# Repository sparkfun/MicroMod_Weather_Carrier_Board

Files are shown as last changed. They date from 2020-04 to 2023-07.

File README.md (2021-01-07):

SparkFun MicroMod Weather Carrier Board
========================================

SparkFun MicroMod Weather Carrier Board

[*SparkFun MicroMod Weather Carrier Board (SEN-16794)*](https://www.sparkfun.com/products/16794)

The MicroMod Weather Carrier Board for the [SparkFun MicroMod Ecosystem](https://www.sparkfun.com/micromod) allows you to create your own weather station with one of a multitude of processors. The carrier board includes three sensors: the BME280 temperature, pressure and humidity sensor, the VEML6075 UV sensor and the AS3935 Lightning detector. There is also a 3-pin latch terminal to add an external [soil moisture sensor](https://www.sparkfun.com/products/13637), a pair RJ11 jacks to plug in the wind and rain sensors included with our [Weather Meter Kit](https://www.sparkfun.com/products/15901) as well as a microSD card slot so you can plug in an SD card to log the weather data.

Repository Contents
-------------------

* **/Documentation** - Data sheets, additional product information 
* **/Hardware** - Eagle design files (.brd, .sch)
* **/Production** - Production panel files (.brd)
* **/Examples** - Arduino examples for the MicroMod Weather Carrier Board

Documentation
--------------
* **Libraries** - Arduino libraries required for the MicroMod Weather Carrier Board.
   * **[BME280 Library](https://github.com/sparkfun/SparkFun_BME280_Arduino_Library)** - Arduino Library for the BME280.
   * **[VEML6075 Library](https://github.com/sparkfun/SparkFun_VEML6075_Arduino_Library)** - Arduino library for the VEML6075.
   * **[AS3935 Library](https://github.com/sparkfun/SparkFun_AS3935_Lightning_Detector_Arduino_Library)** - Arduino library for the AS3935.
* **[Hookup Guide](https://learn.sparkfun.com/tutorials/micromod-weather-carrier-board-hookup-guide)** - Basic hookup guide for the MicroMod Weather Carrier Board.
* **[SparkFun Fritzing repo](https://github.com/sparkfun/Fritzing_Parts)** - Fritzing diagrams for SparkFun products.
* **[SparkFun 3D Model repo](https://github.com/sparkfun/3D_Models)** - 3D models of SparkFun products. 
* **[SparkFun Graphical Datasheets](https://github.com/sparkfun/Graphical_Datasheets)** -Graphical Datasheets for various SparkFun products.

Product Versions
----------------
* [SEN-16794](https://www.sparkfun.com/products/16794)- Initial release of the MicroMod Weather Carrier Board.

License Information
-------------------

This product is _**open source**_! 

Please review the LICENSE.md file for license information. 

If you have any questions or concerns on licensing, please contact technical support on our [SparkFun forums](https://forum.sparkfun.com/viewforum.php?f=152).

Distributed as-is; no warranty is given.

- Your friends at SparkFun.

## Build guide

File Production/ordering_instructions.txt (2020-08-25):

panel size, 169x125mm
PCB thickness, 1.6mm
number of layers, 2
soldermask color, Red
silkscreen color, White
oz copper, 1oz
finish, HASL lead free
stencils, top
pcs per panel, 4
min trace width, 0.2032mm / 0.0080in
min drill size, 0.3048mm / 0.0120in

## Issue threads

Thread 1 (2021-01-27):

Davis Anemometer

dartmoordunbar, 2021-01-27:
Is there any way to use a Davis instruments Anemometer with this?

makin-stuff, 2022-01-18:
Hi there @dartmoordunbar. The MM Weather CB and the Arduino examples in this repo are specifically designed for this weather meter: https://www.sparkfun.com/products/15901
Simply plug the connectors into the RJ11 jacks.

Closed 2022-01-18.

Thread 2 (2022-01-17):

MM_Weather_CB_Test code does not compile for Artemis module.

phillipjohnston, 2022-01-17:
```
/Users/phillip/src/ea/projects/MicroMod_Weather_Carrier_Board/Examples/MM_Weather_CB_Test/MM_Weather_CB_Test.ino: In function 'void setup()':
MM_Weather_CB_Test:116:3: error: 'interrupts' was not declared in this scope
   interrupts();
   ^~~~~~~~~~
/Users/phillip/src/ea/projects/MicroMod_Weather_Carrier_Board/Examples/MM_Weather_CB_Test/MM_Weather_CB_Test.ino:116:3: note: suggested alternative: 'intptr_t'
   interrupts();
   ^~~~~~~~~~
   intptr_t
```

This is using the Apollo3 boards package 2.2.0, witih the Artemis Micromod Processor selected.

Library versions:

```
  -> candidates: [SPI@2.0.0]
/Users/phillip/Library/Arduino15/packages/SparkFun/tools/arm-none-eabi-gcc/8-2018-q4-major/bin/arm-none-eabi-g++ -include /Users/phillip/Library/Arduino15/packages/SparkFun/hardware/apollo3/2.2.0/variants/SFE_ARTEMIS_MM_PB/mbed/mbed_config.h -include /Users/phillip/Library/Arduino15/packages/SparkFun/hardware/apollo3/2.2.0/cores/arduino/sdk/ArduinoSDK.h -iprefix /Users/phillip/Library/Arduino15/packages/SparkFun/hardware/apollo3/2.2.0/cores/ @/Users/phillip/Library/Arduino15/packages/SparkFun/hardware/apollo3/2.2.0/variants/SFE_ARTEMIS_MM_PB/mbed/.cxx-flags -w -x c++ -E -CC -DARDUINO=10819 -DARDUINO_APOLLO3_SFE_ARTEMIS_MM_PB -DARDUINO_ARCH_MBED -DARDUINO_ARCH_APOLLO3 -DMBED_NO_GLOBAL_USING_DIRECTIVE -DCORDIO_ZERO_COPY_HCI @/Users/phillip/Library/Arduino15/packages/SparkFun/hardware/apollo3/2.2.0/variants/SFE_ARTEMIS_MM_PB/mbed/.cxx-symbols -I/Users/phillip/Library/Arduino15/packages/SparkFun/hardware/apollo3/2.2.0/cores/arduino -I/Users/phillip/Library/Arduino15/packages/SparkFun/hardware/apollo3/2.2.0/variants/SFE_ARTEMIS_MM_PB -I/Users/phillip/Library/Arduino15/packages/SparkFun/hardware/apollo3/2.2.0/libraries/Wire/src -I/Users/phillip/Library/Arduino15/packages/SparkFun/hardware/apollo3/2.2.0/libraries/SPI/src -I/Users/phillip/Library/Arduino15/packages/SparkFun/hardware/apollo3/2.2.0/cores/arduino -I/Users/phillip/Library/Arduino15/packages/SparkFun/hardware/apollo3/2.2.0/cores/arduino/mbed-bridge -I/Users/phillip/Library/Arduino15/packages/SparkFun/hardware/apollo3/2.2.0/cores/arduino/mbed-bridge/core-api -I/Users/phillip/Library/Arduino15/packages/SparkFun/hardware/apollo3/2.2.0/cores/arduino/mbed-bridge/core-api/api/deprecated @/Users/phillip/Library/Arduino15/packages/SparkFun/hardware/apollo3/2.2.0/variants/SFE_ARTEMIS_MM_PB/mbed/.includes /var/folders/t_/9hrr7dnd7g5gqkc3lnlv0qx40000gn/T/arduino_build_899532/sketch/MM_Weather_CB_Test.ino.cpp -o /dev/null
Alternatives for SparkFunBME280.h: [SparkFun_BME280@2.0.9]
ResolveLibrary(SparkFunBME280.h)
  -> candidates: [SparkFun_BME280@2.0.9]
/Users/phillip/Library/Arduino15/packages/SparkFun/tools/arm-none-eabi-gcc/8-2018-q4-major/bin/arm-none-eabi-g++ -include /Users/phillip/Library/Arduino15/packages/SparkFun/hardware/apollo3/2.2.0/variants/SFE_ARTEMIS_MM_PB/mbed/mbed_config.h -include /Users/phillip/Library/Arduino15/packages/SparkFun/hardware/apollo3/2.2.0/cores/arduino/sdk/ArduinoSDK.h -iprefix /Users/phillip/Library/Arduino15/packages/SparkFun/hardware/apollo3/2.2.0/cores/ @/Users/phillip/Library/Arduino15/packages/SparkFun/hardware/apollo3/2.2.0/variants/SFE_ARTEMIS_MM_PB/mbed/.cxx-flags -w -x c++ -E -CC -DARDUINO=10819 -DARDUINO_APOLLO3_SFE_ARTEMIS_MM_PB -DARDUINO_ARCH_MBED -DARDUINO_ARCH_APOLLO3 -DMBED_NO_GLOBAL_USING_DIRECTIVE -DCORDIO_ZERO_COPY_HCI @/Users/phillip/Library/Arduino15/packages/SparkFun/hardware/apollo3/2.2.0/variants/SFE_ARTEMIS_MM_PB/mbed/.cxx-symbols -I/Users/phillip/Library/Arduino15/packages/SparkFun/hardware/apollo3/2.2.0/cores/arduino -I/Users/phillip/Library/Arduino15/packages/SparkFun/hardware/apollo3/2.2.0/variants/SFE_ARTEMIS_MM_PB -I/Users/phillip/Library/Arduino15/packages/SparkFun/hardware/apollo3/2.2.0/libraries/Wire/src -I/Users/phillip/Library/Arduino15/packages/SparkFun/hardware/apollo3/2.2.0/libraries/SPI/src -I/Users/phillip/Documents/Arduino/libraries/SparkFun_BME280/src -I/Users/phillip/Library/Arduino15/packages/SparkFun/hardware/apollo3/2.2.0/cores/arduino -I/Users/phillip/Library/Arduino15/packages/SparkFun/hardware/apollo3/2.2.0/cores/arduino/mbed-bridge -I/Users/phillip/Library/Arduino15/packages/SparkFun/hardware/apollo3/2.2.0/cores/arduino/mbed-bridge/core-api -I/Users/phillip/Library/Arduino15/packages/SparkFun/hardware/apollo3/2.2.0/cores/arduino/mbed-bridge/core-api/api/deprecated @/Users/phillip/Library/Arduino15/packages/SparkFun/hardware/apollo3/2.2.0/variants/SFE_ARTEMIS_MM_PB/mbed/.includes /var/folders/t_/9hrr7dnd7g5gqkc3lnlv0qx40000gn/T/arduino_build_899532/sketch/MM_Weather_CB_Test.ino.cpp -o /dev/null
Alternatives for SparkFun_VEML6075_Arduino_Library.h: [SparkFun_VEML6075_Arduino_Library@1.1.4]
ResolveLibrary(SparkFun_VEML6075_Arduino_Library.h)
  -> candidates: [SparkFun_VEML6075_Arduino_Library@1.1.4]
/Users/phillip/Library/Arduino15/packages/SparkFun/tools/arm-none-eabi-gcc/8-2018-q4-major/bin/arm-none-eabi-g++ -include /Users/phillip/Library/Arduino15/packages/SparkFun/hardware/apollo3/2.2.0/variants/SFE_ARTEMIS_MM_PB/mbed/mbed_config.h -include /Users/phillip/Library/Arduino15/packages/SparkFun/hardware/apollo3/2.2.0/cores/arduino/sdk/ArduinoSDK.h -iprefix /Users/phillip/Library/Arduino15/packages/SparkFun/hardware/apollo3/2.2.0/cores/ @/Users/phillip/Library/Arduino15/packages/SparkFun/hardware/apollo3/2.2.0/variants/SFE_ARTEMIS_MM_PB/mbed/.cxx-flags -w -x c++ -E -CC -DARDUINO=10819 -DARDUINO_APOLLO3_SFE_ARTEMIS_MM_PB -DARDUINO_ARCH_MBED -DARDUINO_ARCH_APOLLO3 -DMBED_NO_GLOBAL_USING_DIRECTIVE -DCORDIO_ZERO_COPY_HCI @/Users/phillip/Library/Arduino15/packages/SparkFun/hardware/apollo3/2.2.0/variants/SFE_ARTEMIS_MM_PB/mbed/.cxx-symbols -I/Users/phillip/Library/Arduino15/packages/SparkFun/hardware/apollo3/2.2.0/cores/arduino -I/Users/phillip/Library/Arduino15/packages/SparkFun/hardware/apollo3/2.2.0/variants/SFE_ARTEMIS_MM_PB -I/Users/phillip/Library/Arduino15/packages/SparkFun/hardware/apollo3/2.2.0/libraries/Wire/src -I/Users/phillip/Library/Arduino15/packages/SparkFun/hardware/apollo3/2.2.0/libraries/SPI/src -I/Users/phillip/Documents/Arduino/libraries/SparkFun_BME280/src -I/Users/phillip/Documents/Arduino/libraries/SparkFun_VEML6075_Arduino_Library/src -I/Users/phillip/Library/Arduino15/packages/SparkFun/hardware/apollo3/2.2.0/cores/arduino -I/Users/phillip/Library/Arduino15/packages/SparkFun/hardware/apollo3/2.2.0/cores/arduino/mbed-bridge -I/Users/phillip/Library/Arduino15/packages/SparkFun/hardware/apollo3/2.2.0/cores/arduino/mbed-bridge/core-api -I/Users/phillip/Library/Arduino15/packages/SparkFun/hardware/apollo3/2.2.0/cores/arduino/mbed-bridge/core-api/api/deprecated @/Users/phillip/Library/Arduino15/packages/SparkFun/hardware/apollo3/2.2.0/variants/SFE_ARTEMIS_MM_PB/mbed/.includes /var/folders/t_/9hrr7dnd7g5gqkc3lnlv0qx40000gn/T/arduino_build_899532/sketch/MM_Weather_CB_Test.ino.cpp -o /dev/null
Alternatives for SparkFun_AS3935.h: [SparkFun_AS3935_Lightning_Detector_Arduino_Library@1.4.3]
ResolveLibrary(SparkFun_AS3935.h)
  -> candidates: [SparkFun_AS3935_Lightning_Detector_Arduino_Library@1.4.3]
```

phillipjohnston, 2022-01-17:
Related to: https://github.com/sparkfun/Arduino_Apollo3/issues/431

Of course, commenting out resolves compilation, but I do not understand the core/example/library implementations enough to know whether this introduces unexpected behavior.

santaimpersonator, 2022-03-31:
@phillipjohnston

We implemented a fix (https://github.com/sparkfun/Arduino_Apollo3/issues/431#issuecomment-1071055401) for the interrupt enable/disable functions. Please try updating the Arduino core version, in the Board Manager, before re-uploading the code to your processor board.

If you let us know which [example](https://github.com/sparkfun/MicroMod_Weather_Carrier_Board/tree/master/Examples) you are using and provide a screenshot (or copy) of the output in the Serial Monitor, I can at least try to verify that we am seeing the something similar with a test setup.

phillipjohnston, 2022-05-05:
Confirmed the example now compiles without modification.

Closed 2022-05-05.

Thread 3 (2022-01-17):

Wind direction interpretation clearly not degrees

phillipjohnston, 2022-01-17:
Is the wind direction supposed to correspond to degrees? When I try to use the example with an ESP32, 75% of the range returns a value of -1, and the remaining 25% is all over the place. With an Artemis, I only get numbers in specific ranges - never anything representing 0-180.

makin-stuff, 2022-01-18:
Hello @phillipjohnston. Are you plugging in a weather meter to the RJ11 jacks?  The hardware and Arduino examples are designed specifically for this one: https://www.sparkfun.com/products/15901

phillipjohnston, 2022-01-18:
Yep, that's the one I'm using!

phillipjohnston, 2022-05-05:
I am using `MM_Weather_CB_Test` to check this behavior. With the latest Apollo3 board files update, the behavior is different. I now see values in the range of [0, 300] (never get above 300). However, the wind direction still does not seem to correspond to a consistent set of readings as far as I can tell - for example, I can never find any degrees above 300, and there only seems to be a few values that ever get reported, regardless of how precisely I turn the wind vane: 113, 23, 224, 248 are common values that appear. It is hard to see anything obvious in this from the log without a corresponding video setup showing how things are being turned on the weather vane... but I do not have a good recording setup to get all of that.

Log sample:

```
10:34:41.746 -> Temperature: 79.39
10:34:41.746 -> Humidity: 31
10:34:41.784 -> Pressure: 88734
10:34:41.784 -> Altitude: 3625.9
10:34:41.784 -> UV A, B, index: %4.2f, %4.2f, %4.2f
10:34:41.784 -> Soil Moisture = 122
10:34:41.784 -> Wind direction: 113 degrees
10:34:44.817 ->
10:34:47.851 ->
10:34:47.851 -> Temperature: 79.38
10:34:47.851 -> Humidity: 31
10:34:47.851 -> Pressure: 88730
10:34:47.851 -> Altitude: 3627.2
10:34:47.851 -> UV A, B, index: %4.2f, %4.2f, %4.2f
10:34:47.851 -> Soil Moisture = 173
10:34:47.885 -> Wind direction: 23 degrees
10:34:47.885 -> Rain click!
10:34:47.885 -> Disturber.
10:34:50.889 ->
10:34:53.958 ->
10:34:56.985 ->
10:34:56.985 -> Temperature: 79.34
10:34:56.985 -> Humidity: 31
10:34:56.985 -> Pressure: 88730
10:34:56.985 -> Altitude: 3626.9
10:34:56.985 -> UV A, B, index: %4.2f, %4.2f, %4.2f
10:34:56.985 -> Soil Moisture = 200
10:34:57.019 -> Wind direction: 45 degrees
10:34:57.019 -> Rain click!
10:35:00.022 ->
10:35:00.022 -> Temperature: 79.34
10:35:00.022 -> Humidity: 31
10:35:00.022 -> Pressure: 88727
10:35:00.022 -> Altitude: 3628.0
10:35:00.022 -> UV A, B, index: %4.2f, %4.2f, %4.2f
10:35:00.060 -> Soil Moisture = 132
10:35:00.060 -> Wind direction: 0 degrees
10:35:03.090 ->
10:35:03.090 -> Temperature: 79.32
10:35:03.090 -> Humidity: 31
10:35:03.090 -> Pressure: 88731
10:35:03.090 -> Altitude: 3626.7
10:35:03.090 -> UV A, B, index: %4.2f, %4.2f, %4.2f
10:35:03.090 -> Soil Moisture = 252
10:35:03.090 -> Wind direction: 0 degrees
10:35:06.123 ->
10:35:09.157 ->
10:35:12.209 -> Temperature: 79.27
10:35:12.209 -> Humidity: 31
10:35:12.209 -> Pressure: 88733
10:35:12.209 -> Altitude: 3626.0
10:35:12.209 -> UV A, B, index: %4.2f, %4.2f, %4.2f
10:35:12.209 -> Soil Moisture = 219
10:35:12.242 -> Wind direction: 23 degrees
10:35:12.242 -> Rain click!
10:35:12.242 -> Disturber.
10:35:15.237 ->
10:35:18.285 ->
10:35:24.386 ->
10:35:30.474 ->
10:35:42.651 ->
10:35:48.727 ->
10:36:13.090 ->
10:36:16.139 ->
10:36:16.139 -> Temperature: 79.32
10:36:16.139 -> Humidity: 31
10:36:16.139 -> Pressure: 88731
10:36:16.139 -> Altitude: 3626.7
10:36:16.139 -> UV A, B, index: %4.2f, %4.2f, %4.2f
10:36:16.139 -> Soil Moisture = 254
10:36:16.139 -> Wind direction: 248 degrees
10:36:16.139 -> Rain click!
10:36:19.171 ->
10:36:25.269 ->
10:36:25.269 -> Temperature: 79.30
10:36:25.269 -> Humidity: 31
10:36:25.269 -> Pressure: 88730
10:36:25.269 -> Altitude: 3627.1
10:36:25.269 -> UV A, B, index: %4.2f, %4.2f, %4.2f
10:36:25.269 -> Soil Moisture = 264
10:36:25.269 -> Wind direction: 248 degrees
10:36:49.600 ->
10:36:49.600 -> Temperature: 79.30
10:36:49.600 -> Humidity: 31
10:36:49.600 -> Pressure: 88736
10:36:49.600 -> Altitude: 3625.4
10:36:49.600 -> UV A, B, index: %4.2f, %4.2f, %4.2f
10:36:49.637 -> Soil Moisture = 133
10:36:49.637 -> Wind direction: 113 degrees
10:36:49.637 -> Rain click!
10:36:52.666 ->
10:36:52.666 -> Temperature: 79.30
10:36:52.666 -> Humidity: 31
10:36:52.666 -> Pressure: 88730
10:36:52.666 -> Altitude: 3627.1
10:36:52.666 -> UV A, B, index: %4.2f, %4.2f, %4.2f
10:36:52.666 -> Soil Moisture = 149
10:36:52.666 -> Wind direction: 113 degrees
10:36:55.707 ->
10:36:55.707 -> Temperature: 79.29
10:36:55.707 -> Humidity: 31
10:36:55.707 -> Pressure: 88735
10:36:55.707 -> Altitude: 3625.6
10:36:55.707 -> UV A, B, index: %4.2f, %4.2f, %4.2f
10:36:55.707 -> Soil Moisture = 270
10:36:55.707 -> Wind direction: 113 degrees
10:36:58.752 ->
10:36:58.752 -> Temperature: 79.29
10:36:58.752 -> Humidity: 31
10:36:58.752 -> Pressure: 88734
10:36:58.752 -> Altitude: 3625.8
10:36:58.752 -> UV A, B, index: %4.2f, %4.2f, %4.2f
10:36:58.752 -> Soil Moisture = 251
10:36:58.752 -> Wind direction: 248 degrees
10:36:58.789 -> Rain click!
10:36:58.789 -> Disturber.
10:37:01.804 ->
10:37:01.804 -> Temperature: 79.25
10:37:01.804 -> Humidity: 31
10:37:01.804 -> Pressure: 88731
10:37:01.804 -> Altitude: 3626.7
10:37:01.804 -> UV A, B, index: %4.2f, %4.2f, %4.2f
10:37:01.804 -> Soil Moisture = 241
10:37:01.804 -> Wind direction: 248 degrees
```

phillipjohnston, 2022-05-05:
Now, it may very well be that the interrupt behavior reported in #4 is messing with things.

makin-stuff, 2022-05-05:
Hi there @phillipjohnston. I would highly recommend checking out the documentation on the weather meter ([hookup guide](https://learn.sparkfun.com/tutorials/weather-meter-hookup-guide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) and [datasheet](https://cdn.sparkfun.com/assets/d/1/e/0/6/DS-15901-Weather_Meter.pdf)).

The wind vane basically functions as a voltage divider. So I think you would want to read the analog voltage on the WDIR/A1 pin. Then, the voltage divider equation is: Vo = (Vi*R2)/(R1+R2). Vo is measured from A1, Vi = 3.3V, and R1 is 10k (from schematic). You can calculate R2 and look it up in this table from the datasheet:
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

Hope this helps!

phillipjohnston, 2022-05-05:
Right, I'm happy to do that myself. I'm just pointing out that the example code doesn't work as expected.

phillipjohnston, 2022-05-05:
Although, now that I reread the reviews on the product page (https://www.sparkfun.com/products/15901), I see that this behavior is observed by others and maybe that's just the best it can be.

santaimpersonator, 2023-06-16:
@phillipjohnston
The ADC on the ESP32 is non-linear, which causes issues with the readings. I'd recommend reading and printing out the ADC values, while spinning the wind vane around. If you create a histogram chart (binsize<20), you should be able to see distinct peaks of the indicated directions (which would allow you to fix the example code).

Also, it has a 12-bit ADC (0-4095).

Closed 2022-05-05.

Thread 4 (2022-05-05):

MM_Weather_CB_Test panic if interrupts are enabled.

phillipjohnston, 2022-05-05:
After #2, the code compiles without modification. However, the application panics when interrupts are enabled. Commenting it out removes this error.

```
10:32:47.098 -> ++ MbedOS Error Info ++
10:32:47.098 -> Error Status: 0x80FF0144 Code: 324 Module: 255
10:32:47.098 -> Error Message: Assertion failed: status == osOK
10:32:47.098 -> Location: 0x24EE9
10:32:47.098 -> File: mbed-os/rtos/source/ThisThread.cpp+225
10:32:47.098 -> Error Value: 0x0
10:32:47.098 -> Current Thread: main Id: 0x100048E0 Entry: 0x25EF1 StackSize: 0x1000 StackMem: 0x10006560 SP: 0x100074BC
10:32:47.098 -> For more info, visit: https://mbed.com/s/error?error=0x80FF0144&tgt=SFE_ARTEMIS_MM_PB
10:32:47.134 -> -- MbedOS Error Info --
```

makin-stuff, 2022-05-05:
Hi there @phillipjohnston. I'm closing this issue because this error has nothing to do with the hardware of the MM Weather CB but with the processor board your are using with it. Can you please repost this issue on the corresponding github repo for the processor you're using? Thank you.

Closed 2022-05-05.

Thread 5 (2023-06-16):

Feature Request - Battery charger/connector

santaimpersonator, 2023-06-16:
For remote applications, include a battery charger and connector.

That way a [USB solar panel](https://www.sparkfun.com/products/16835) can be connected. Also, we don't have a solar charging solution with a 3.3V output to connect to the board.

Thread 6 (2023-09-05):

Feature Request: 5V/V_USB pin

santaimpersonator, 2023-09-05:
A [customer requested](https://www.sparkfun.com/news/7930#comment-64f7749be550b931fa19f573) that we breakout a `5V` (or `V_USB`) pin on the board.

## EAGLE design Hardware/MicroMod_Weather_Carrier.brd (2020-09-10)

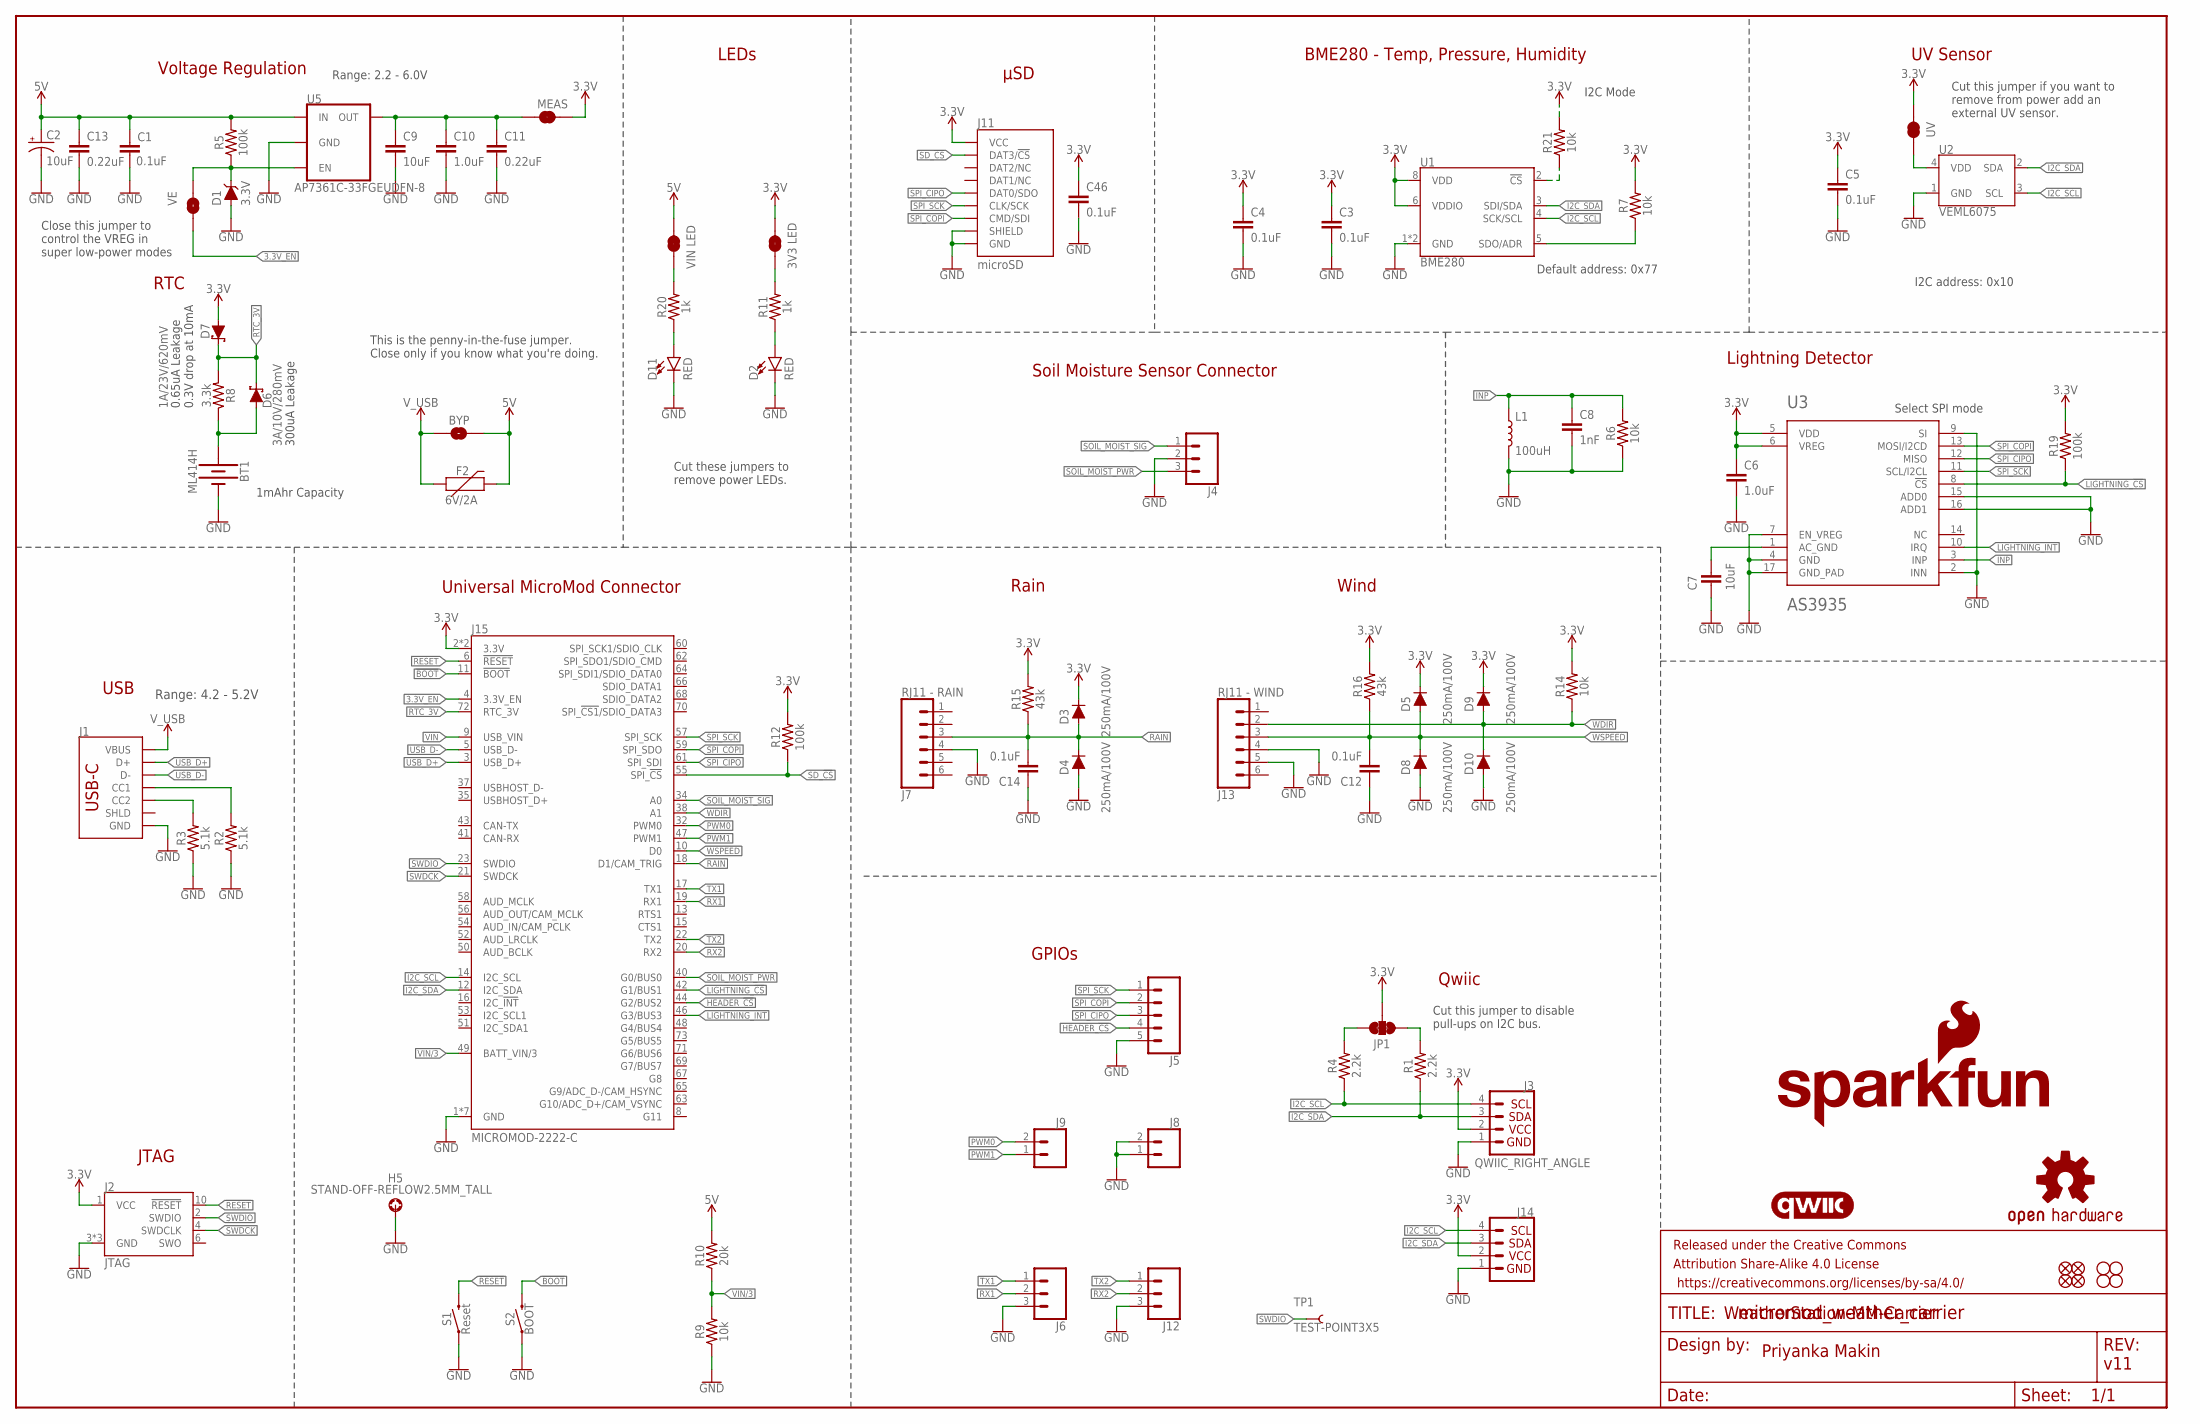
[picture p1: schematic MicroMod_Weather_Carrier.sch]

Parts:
BT1: ML414H; ML414H_IV01E
BYP: JUMPER-SMT_2_NO_SILK; SMT-JUMPER_2_NO_SILK
C1, C3, C4, C5, C12, C14, C46: 0.1uF; 0603
C2: 10uF; EIA3216
C6, C10: 1.0uF; 0603
C7, C9: 10uF; 0603
C8: 1nF; 0603
C11, C13: 0.22uF; 0603
D1: 3.3V; SOD-323
D2, D11: RED; LED-0603
D3, D4, D5, D8, D9, D10: 250mA/100V; SOD-323
D6: 3A/10V/280mV; SOD-323
D7: 1A/23V/620mV; SOD-323
F2: 6V/2A; 1210
FD1, FD2, FD3, FD4: FIDUCIALUFIDUCIAL; FIDUCIAL-MICRO
FRAME1: FRAME-LEDGER; CREATIVE_COMMONS
H1, H2, H3, H4: STAND-OFF
H5: STAND-OFF-REFLOW2.5MM_TALL; STAND-OFF-REFLOW-M2.5
J1: USB_C_2-LAYER_PADS; USB-C-16P-2LAYER-PADS
J2: JTAG; 2X5-PTH-1.27MM
J3: QWIIC_RIGHT_ANGLE; JST04_1MM_RA
J4: CONN_03LATCH; LATCHTERMINAL-5MM-3
J5: CONN_05NO_SILK; 1X05_NO_SILK
J6, J12: CONN_031X03_NO_SILK; 1X03_NO_SILK
J7: RJ11 - RAIN; RJ11-6
J8, J9: CONN_021X02_NO_SILK; 1X02_NO_SILK
J11: microSD; MICRO-SD-SOCKET
J13: RJ11 - WIND; RJ11-6
J14: I2C_STANDARD_NO_SILK; 1X04_NO_SILK
J15: MICROMOD-2222-C; M.2-CONNECTOR-E
JP1: JUMPER-SMT_3_2-NC_TRACE_SILK; SMT-JUMPER_3_2-NC_TRACE_SILK
JP2: VIN LED; SMT-JUMPER_2_NC_TRACE_SILK
JP3: UV; SMT-JUMPER_2_NC_TRACE_SILK
JP4: 3V3 LED; SMT-JUMPER_2_NC_TRACE_SILK
JP6: VE; SMT-JUMPER_2_NO_SILK
L1: 100uH; MA5532-AE
LOGO1: SFE_LOGO_NAME_FLAME.2_INCH; SFE_LOGO_NAME_FLAME_.2
LOGO2: QWIIC_LOGO_CONNECTOR; QWIIC_5.5MM
LOGO3: OSHW-LOGOM; OSHW-LOGO-M
MEAS: JUMPER-COMBO_2_NC_TRACE; COMBO-JUMPER_2_NC_TRACE
R1, R4: 2.2k; 0603
R2, R3: 5.1k; 0603
R5, R12, R19: 100k; 0603
R6, R7, R9, R14, R21: 10k; 0603
R8: 3.3k; 0603
R10: 20k; 0603
R11, R20: 1k; 0603
R15, R16: 43k; 0603
S1: Reset; TACTILE_SWITCH_SMD_5.2MM
S2: BOOT; TACTILE_SWITCH_SMD_5.2MM
TP1: TEST-POINT3X5; PAD.03X.05
U1: BME280; LGA-8-2.5X2.5
U2: VEML6075; VEML6075_A3OP
U3: AS3935; 16LD_MLPQ
U5: AP7361C-33FGEUDFN-8; UDFN-8

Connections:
3.3V: C3.1, C4.1, C5.1, C6.1, C46.1, D3.C, D5.C, D7.A, D9.C, J2.1 (VCC), J3.2, J11.VCC, J14.2, J15.2 (3.3V), J15.74 (3.3V), JP1.2, JP3.2, JP4.2, MEAS.2, MEAS.4 (2), R7.2, R12.2, R14.2, R15.2, R16.2, R19.2, R21.2, U1.6 (VDDIO), U1.8 (VDD), U3.5 (VDD), U3.6 (VREG)
3.3V_EN: J15.4 (3.3V_EN), JP6.1
!BOOT!: J15.11 (!BOOT!), S2.3 (2), S2.4 (2)
!RESET!: J2.10 (!RESET), J15.6 (!RESET!), S1.3 (2), S1.4 (2)
GND: BT1.-, C1.2, C2.-, C3.2, C4.2, C5.2, C6.2, C7.2, C8.2, C9.2, C10.2, C11.2, C12.1, C13.2, C14.1, C46.2, D1.A, D2.C, D4.A, D8.A, D10.A, D11.C, H5.1, J1.GND, J1.GND2 (GND), J2.3 (GND), J2.5 (GND), J2.9 (GND), J3.1, J4.2, J5.5, J6.3, J7.4, J8.1, J8.2, J11.CD1 (SHIELD), J11.GND, J11.GND1 (GND), J11.GND3 (GND), J12.3, J13.4, J13.5, J14.1, J15.1 (GND), J15.7 (GND), J15.33 (GND), J15.36 (GND), J15.39 (GND), J15.45 (GND), J15.75 (GND), L1.2, R2.1, R3.1, R6.1, R9.1, S1.1, S1.2 (1), S2.1, S2.2 (1), U1.1 (GND), U1.7 (GND), U2.1 (GND), U3.2 (INN), U3.4 (GND), U3.7 (EN_VREG), U3.9 (SI), U3.15 (ADD0), U3.16 (ADD1), U3.17 (GND_PAD), U5.4 (GND), U5.EP (GND)
HEADER_!CS!: J5.4, J15.44 (G2/BUS2)
I2C_SCL: J3.4, J14.4, J15.14 (I2C_SCL), R4.1, U1.4 (SCK/SCL), U2.3 (SCL)
I2C_SDA: J3.3, J14.3, J15.12 (I2C_SDA), R1.1, U1.3 (SDI/SDA), U2.2 (SDA)
INP: C8.1, L1.1, R6.2, U3.3 (INP)
LIGHTNING_!CS!: J15.42 (G1/BUS1), R19.1, U3.8 (!CS)
LIGHTNING_INT: J15.46 (G3/BUS3), U3.10 (IRQ)
unnamed: C9.1, C10.1, C11.1, MEAS.1, MEAS.3 (1), U5.1 (OUT)
unnamed: JP1.3, R4.2
unnamed: JP1.1, R1.2
unnamed: JP4.1, R11.2
unnamed: JP2.1, R20.2
unnamed: D2.A, R11.1
unnamed: JP3.1, U2.4 (VDD)
unnamed: R7.1, U1.5 (SDO/ADR)
unnamed: J1.A5 (CC1), R2.2
unnamed: J1.B5 (CC2), R3.2
unnamed: BT1.+, D6.A, R8.1
unnamed: C7.1, U3.1 (AC_GND)
unnamed: D11.A, R20.1
unnamed: R21.1, U1.2 (!CS)
PWM0: J9.2, J15.32 (PWM0)
PWM1: J9.1, J15.47 (PWM1)
RAIN: C14.2, D3.A, D4.C, J7.3, J15.18 (D1/CAM_TRIG), R15.1
RTC_3V: D6.C, D7.C, J15.72 (RTC_3V), R8.2
RX1: J6.2, J15.19 (RX1)
RX2: J12.2, J15.20 (RX2)
SD_!CS!: J11.CS/DAT3 (DAT3/!CS!), J15.55 (SPI_!CS!), R12.1
SOIL_MOIST_PWR: J4.3, J15.40 (G0/BUS0)
SOIL_MOIST_SIG: J4.1, J15.34 (A0)
SPI_CIPO: J5.3, J11.DO/DAT0 (DAT0/SDO), J15.61 (SPI_SDI), U3.12 (MISO)
SPI_COPI: J5.2, J11.DI/CMD (CMD/SDI), J15.59 (SPI_SDO), U3.13 (MOSI/I2CD)
SPI_SCK: J5.1, J11.SCLK (CLK/SCK), J15.57 (SPI_SCK), U3.11 (SCL/I2CL)
SWDCK: J2.4 (SWDCLK), J15.21 (SWDCK)
SWDIO: J2.2 (SWDIO), J15.23 (SWDIO), TP1.P$1
TX1: J6.1, J15.17 (TX1)
TX2: J12.1, J15.22 (TX2)
USB_D+: J1.A6 (D+), J1.B6 (D+), J15.3 (USB_D+)
USB_D-: J1.A7 (D-), J1.B7 (D-), J15.5 (USB_D-)
VIN: BYP.2, C1.1, C2.+, C13.1, F2.2, J15.9 (USB_VIN), JP2.2, R5.2, R10.2, U5.8 (IN)
VIN/3: J15.49 (BATT_VIN/3), R9.2, R10.1
VREG_EN: D1.C, JP6.2, R5.1, U5.5 (EN)
V_USB: BYP.1, F2.1, J1.VBUS1 (VBUS), J1.VBUS2 (VBUS)
WDIR: D9.A, D10.C, J13.2, J15.38 (A1), R14.1
WSPEED: C12.2, D5.A, D8.C, J13.3, J15.10 (D0), R16.1

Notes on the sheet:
300uA Leakage
0.65uA Leakage 0.3V drop at 10mA
1mAhr Capacity
This is the penny-in-the-fuse jumper. Close only if you know what you're doing.
JTAG
USB
GPIOs
Qwiic
RTC
Voltage Regulation
Universal MicroMod Connector
Priyanka Makin
WeatherStation-MM-Carrier
BME280 - Temp, Pressure, Humidity
UV Sensor
Soil Moisture Sensor Connector
Rain
Wind
LEDs
Lightning Detector
I2C Mode
Default address: 0x77
I2C address: 0x10
Select SPI mode
v11
Cut this jumper if you want to remove from power add an external UV sensor.
Cut this jumper to disable pull-ups on I2C bus.
Cut these jumpers to remove power LEDs.
μSD
Range: 4.2 - 5.2V
Range: 2.2 - 6.0V
Close this jumper to control the VREG in super low-power modes

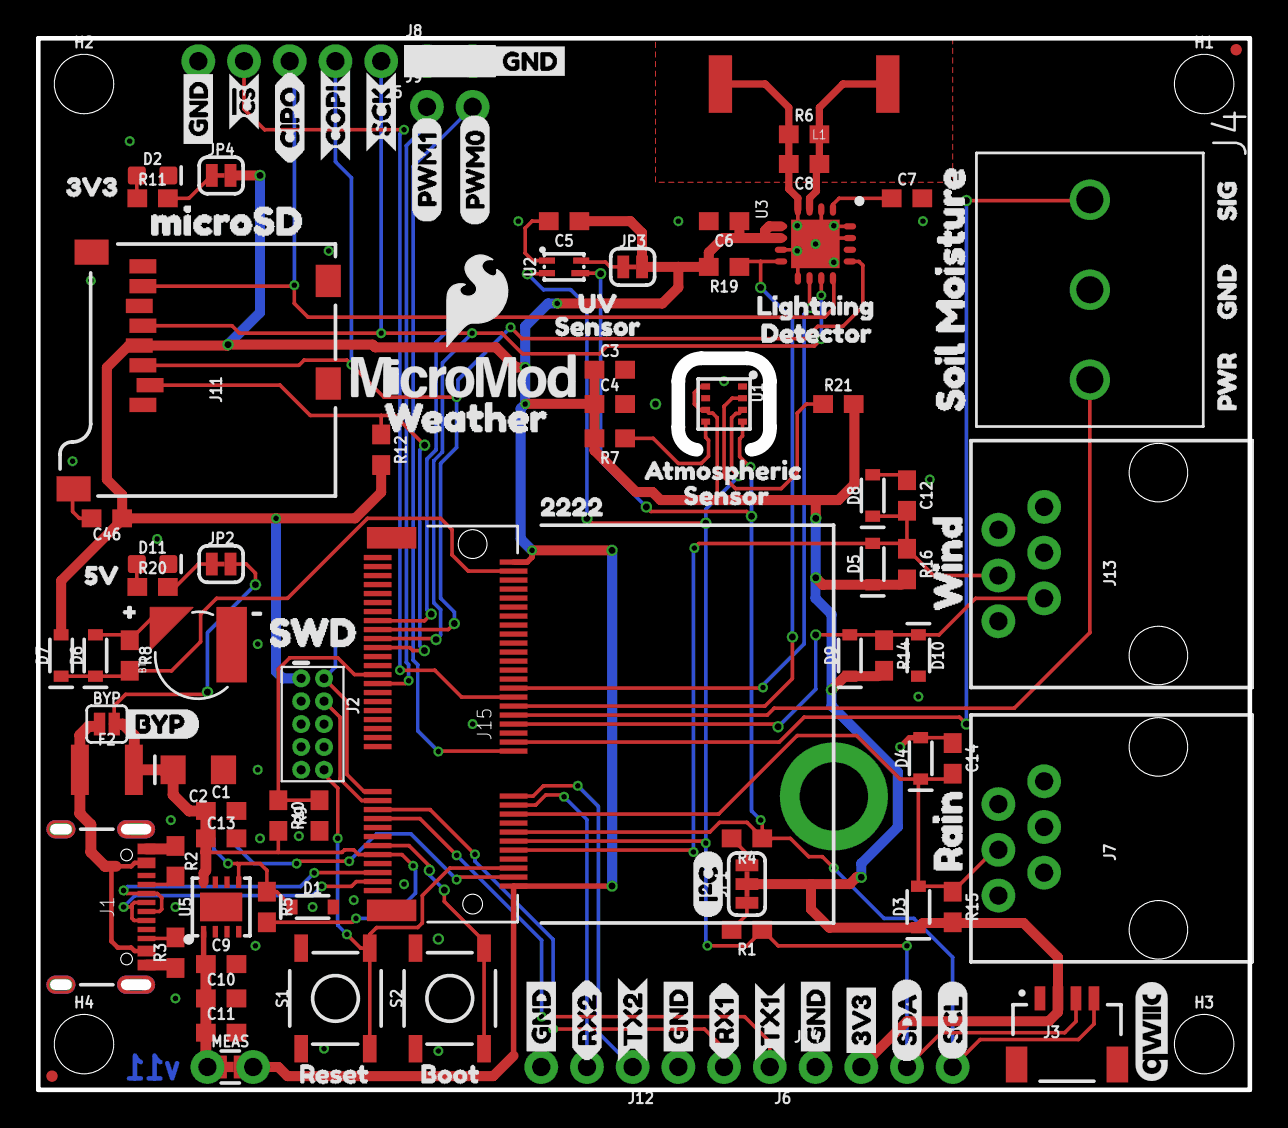
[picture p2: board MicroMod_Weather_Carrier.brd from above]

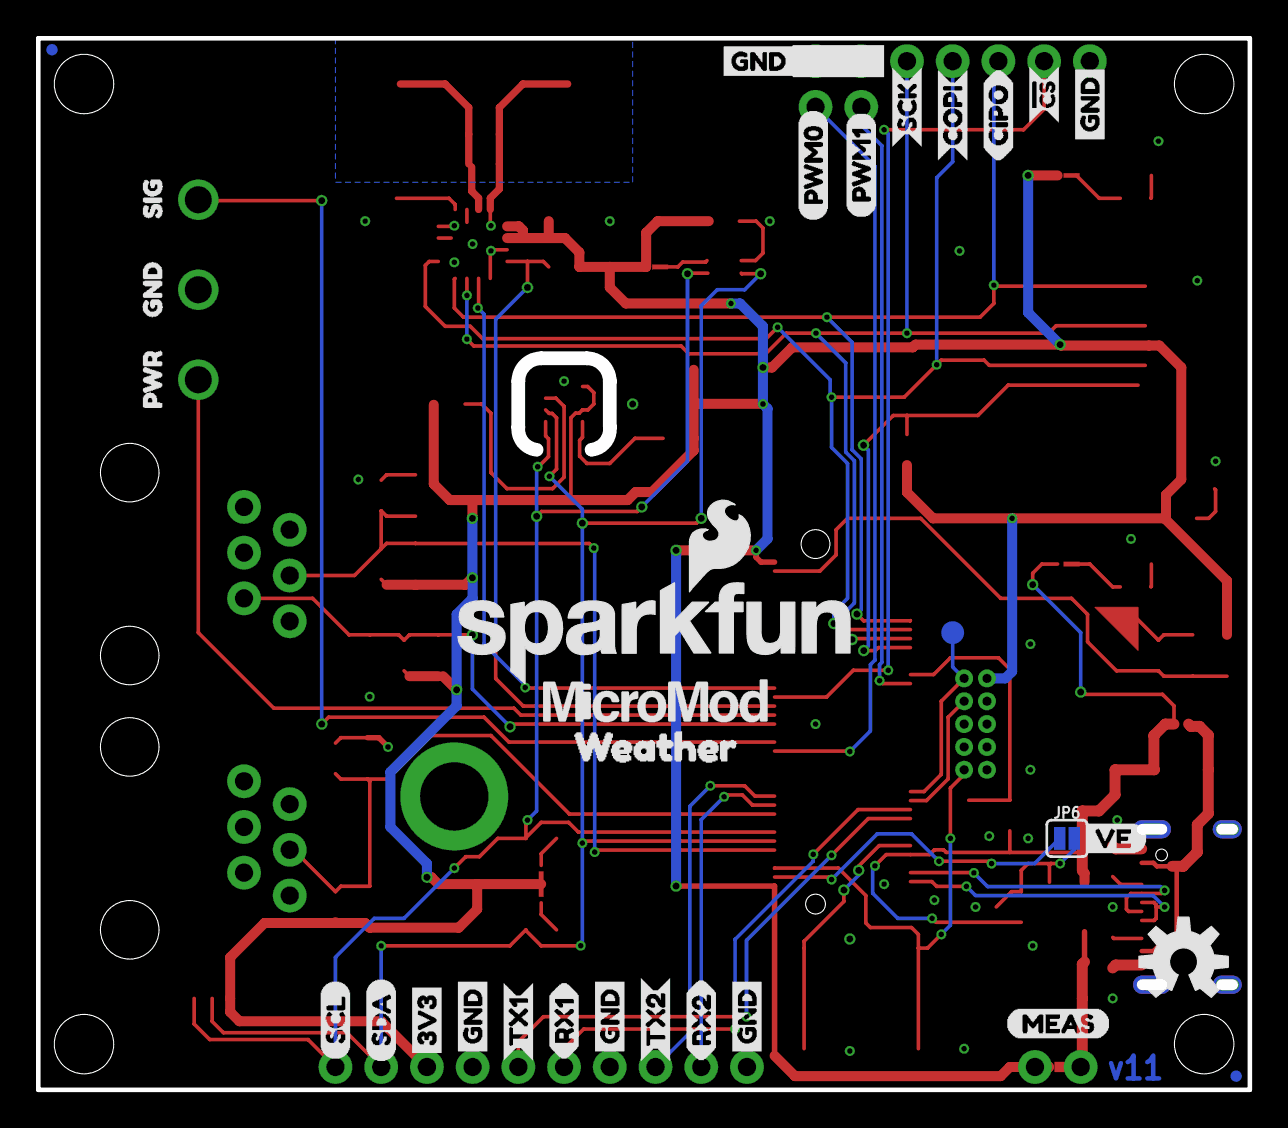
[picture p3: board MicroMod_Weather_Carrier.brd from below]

Board: 2 copper layers, 67.3 x 58.4 mm, 157 parts (31 on the bottom side), 49 nets.

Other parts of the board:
U$1: 3V31
U$2: RESET3
U$3: RAIN1
U$4, U$57: GND0
U$5: MEAS
U$6, U$11, U$23, U$32, U$33, U$36, U$42, U$45, U$53, U$54: GND_P
U$7, U$8: COPI0
U$9, U$49: SCK_O
U$10, U$52: !CS_O
U$12, U$24: PWR2
U$13, U$63: SIG1
U$14: BYP0
U$15, U$61: PWM10
U$16, U$58: WEATHER4
U$17, U$30: RX25
U$18: 5V0
U$19: BOOT2
U$20: ATMOSPHERIC0
U$21: VE0
U$22: LIGHTNING8
U$25, U$29: RX10
U$27, U$50: CIPO0
U$28, U$56: TX24
U$31, U$41: TX13
U$34: SENSOR7
U$35: MICROSD0
U$37: I2C
U$38, U$46: 3V3_P
U$39, U$47: SDA_IO
U$40, U$48: SCL_IO
U$43: SWD1
U$44: SFE_LOGO_FLAME_.2
U$55: 22229
U$59, U$60: PWM01
U$62: UV6
U$64: SENSOR1
U$65: SOIL_MOISTURE2
U$66: WIND0
U$67, U$68: MICROMOD_LOGO_.5
U$69: #0
U$70: #1
U$71: DETECTOR2

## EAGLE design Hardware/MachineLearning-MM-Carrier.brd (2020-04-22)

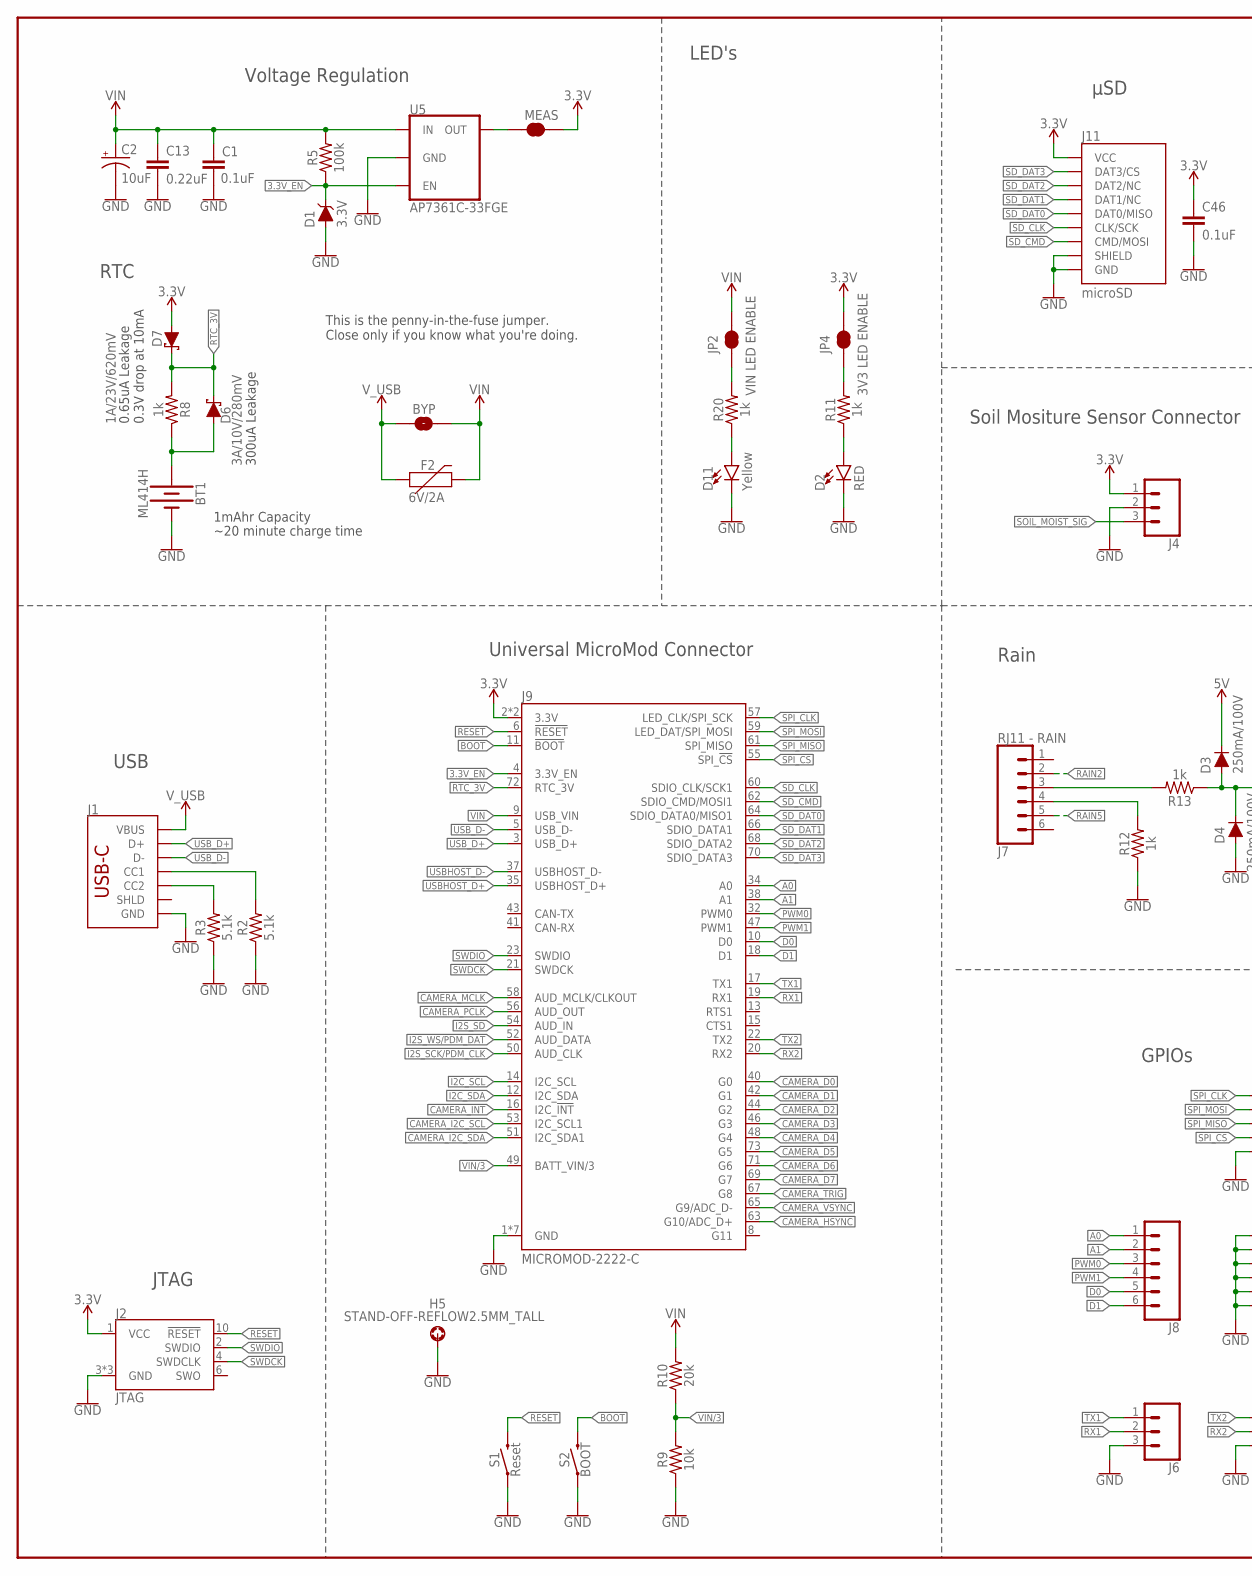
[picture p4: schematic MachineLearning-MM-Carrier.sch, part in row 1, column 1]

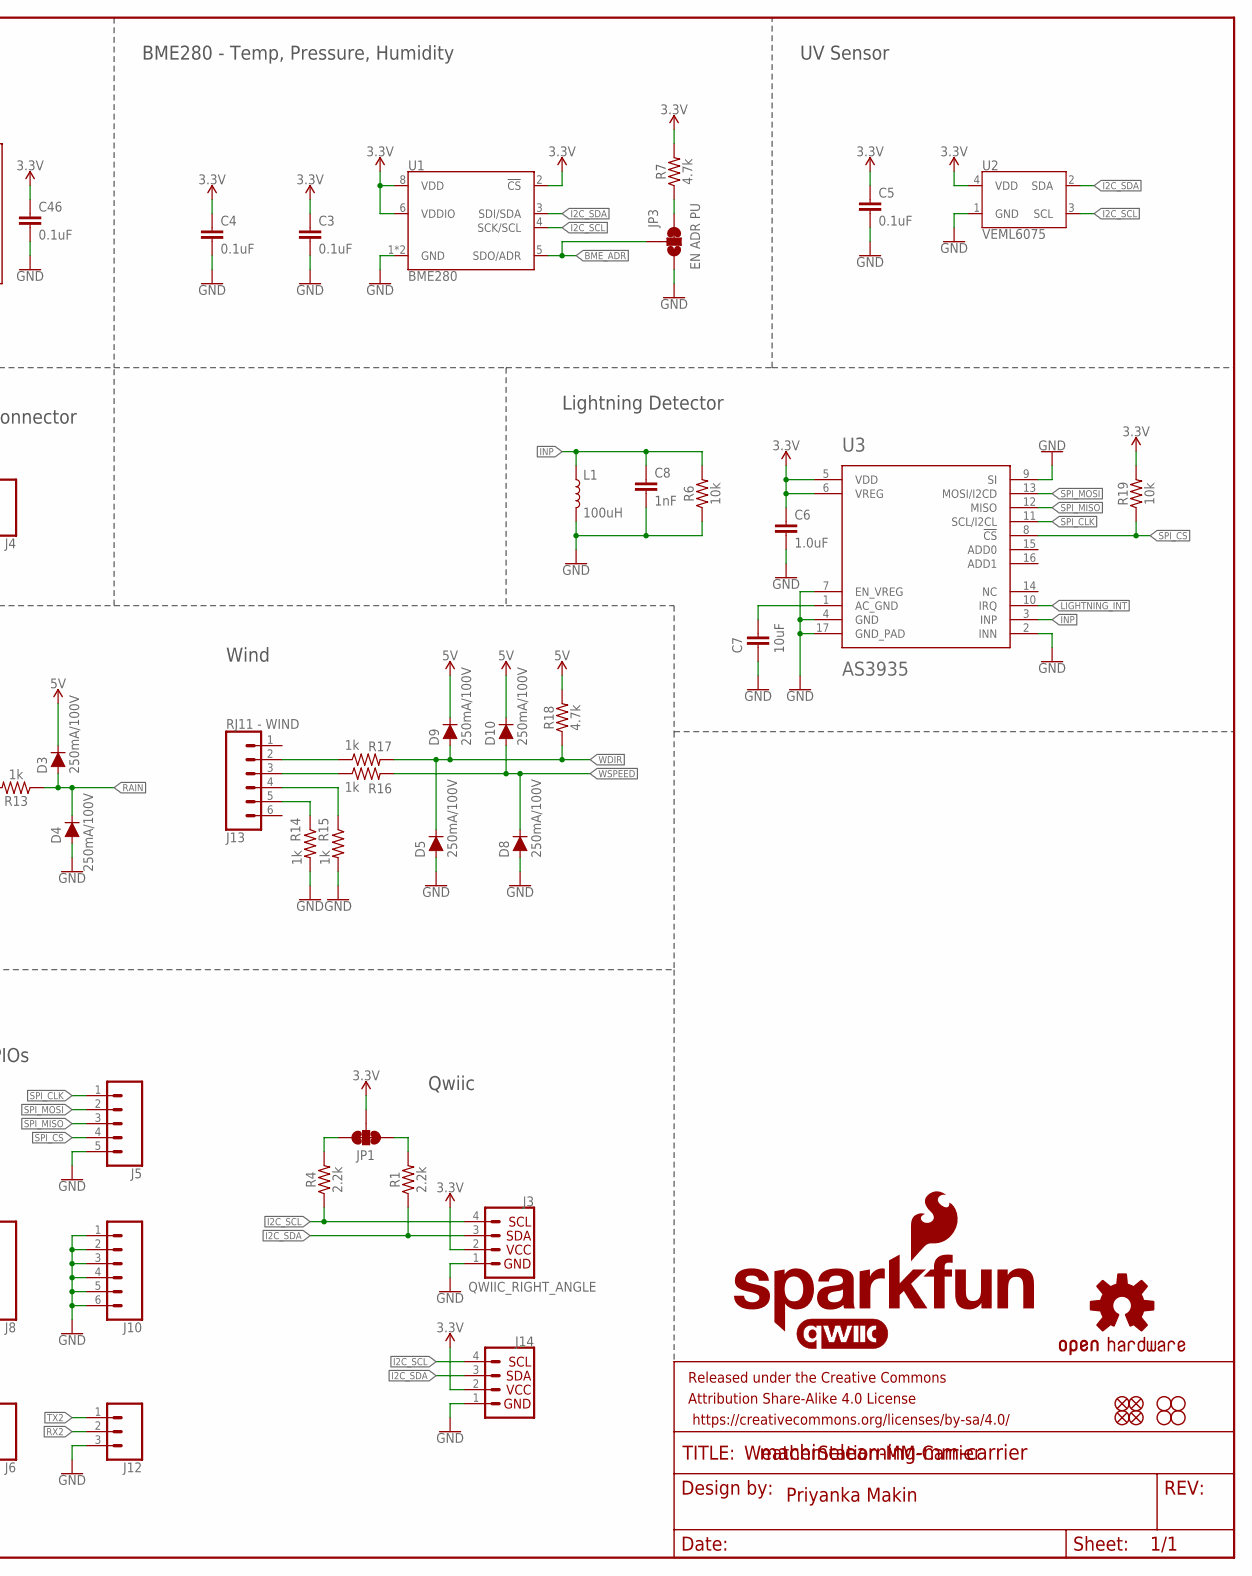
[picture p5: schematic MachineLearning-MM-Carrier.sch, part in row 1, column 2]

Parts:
BT1: ML414H; ML414H_IV01E
BYP: JUMPER-SMT_2_NO_SILK; SMT-JUMPER_2_NO_SILK
C1, C3, C4, C5, C46: 0.1uF; 0603
C2: 10uF; EIA3216
C6: 1.0uF; 0603
C7: 10uF; 0603
C8: 1nF; 0603
C13: 0.22uF; 0603
D1: 3.3V; SOD-323
D2: RED; LED-0603
D3, D4, D5, D8, D9, D10: 250mA/100V; SOD-323
D6: 3A/10V/280mV; SOD-323
D7: 1A/23V/620mV; SOD-323
D11: Yellow; LED-0603
F2: 6V/2A; 1210
FD1, FD2, FD3, FD4: FIDUCIALUFIDUCIAL; FIDUCIAL-MICRO
FRAME1: FRAME-LEDGER; CREATIVE_COMMONS
H1, H2, H3, H4: STAND-OFF
H5: STAND-OFF-REFLOW2.5MM_TALL; STAND-OFF-REFLOW-M2.5
J1: USB_C_2-LAYER_PADS; USB-C-16P-2LAYER-PADS
J2: JTAG; 2X5-PTH-1.27MM
J3: QWIIC_RIGHT_ANGLE; JST04_1MM_RA
J4: CONN_03LATCH; LATCHTERMINAL-5MM-3
J5: CONN_05NO_SILK; 1X05_NO_SILK
J6, J12: CONN_031X03_NO_SILK; 1X03_NO_SILK
J7: RJ11 - RAIN; RJ11-6
J8, J10: CONN_06NO_SILK_NO_POP; 1X06_NO_SILK
J9: MICROMOD-2222-C; M.2-CONNECTOR-E
J11: microSD; MICRO-SD-SOCKET
J13: RJ11 - WIND; RJ11-6
J14: I2C_STANDARD_NO_SILK; 1X04_NO_SILK
JP1: JUMPER-SMT_3_2-NC_TRACE_SILK; SMT-JUMPER_3_2-NC_TRACE_SILK
JP2: VIN LED ENABLE; SMT-JUMPER_2_NC_TRACE_SILK
JP3: EN ADR PU; SMT-JUMPER_3_1-NC_TRACE_SILK
JP4: 3V3 LED ENABLE; SMT-JUMPER_2_NC_TRACE_SILK
L1: 100uH; MA5532-AE
LOGO1: SFE_LOGO_NAME_FLAME.1_INCH; SFE_LOGO_NAME_FLAME_.1
LOGO2: QWIIC_LOGO_CONNECTOR; QWIIC_5.5MM
LOGO3: OSHW-LOGOMINI; OSHW-LOGO-MINI
MEAS: JUMPER-COMBO_2_NC_TRACE; COMBO-JUMPER_2_NC_TRACE
R1, R4: 2.2k; 0603
R2, R3: 5.1k; 0603
R5: 100k; 0603
R6, R9, R19: 10k; 0603
R7, R18: 4.7k; 0603
R8, R11, R12, R13, R14, R15, R16, R17, R20: 1k; 0603
R10: 20k; 0603
S1: Reset; TACTILE_SWITCH_SMD_5.2MM
S2: BOOT; TACTILE_SWITCH_SMD_5.2MM
U1: BME280; LGA-8-2.5X2.5
U2: VEML6075; VEML6075_A3OP
U3: AS3935; 16LD_MLPQ
U5: AP7361C-33FGE; 8-UDFN

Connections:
3.3V: C3.1, C4.1, C5.1, C6.1, C46.1, D7.A, J2.1 (VCC), J3.2, J4.1, J9.2 (3.3V), J9.74 (3.3V), J11.VCC, J14.2, JP1.2, JP4.2, MEAS.2, MEAS.4 (2), R7.2, R19.2, U1.2 (!CS), U1.6 (VDDIO), U1.8 (VDD), U2.4 (VDD), U3.5 (VDD), U3.6 (VREG)
3.3V_EN: D1.C, J9.4 (3.3V_EN), R5.1, U5.5 (EN)
5V: D3.C, D9.C, D10.C, R18.2
!BOOT!: J9.11 (!BOOT!), S2.3 (2), S2.4 (2)
!RESET!: J2.10 (!RESET), J9.6 (!RESET!), S1.3 (2), S1.4 (2)
A0: J8.1, J9.34 (A0)
A1: J8.2, J9.38 (A1)
BME_ADR: JP3.2, U1.5 (SDO/ADR)
CAMERA_D0: J9.40 (G0)
CAMERA_D1: J9.42 (G1)
CAMERA_D2: J9.44 (G2)
CAMERA_D3: J9.46 (G3)
CAMERA_D4: J9.48 (G4)
CAMERA_D5: J9.73 (G5)
CAMERA_D6: J9.71 (G6)
CAMERA_D7: J9.69 (G7)
CAMERA_HSYNC: J9.63 (G10/ADC_D+)
CAMERA_I2C_SCL: J9.53 (I2C_SCL1)
CAMERA_I2C_SDA: J9.51 (I2C_SDA1)
CAMERA_INT: J9.16 (I2C_!INT!)
CAMERA_MCLK: J9.58 (AUD_MCLK/CLKOUT)
CAMERA_PCLK: J9.56 (AUD_OUT)
CAMERA_TRIG: J9.67 (G8)
CAMERA_VSYNC: J9.65 (G9/ADC_D-)
D0: J8.5, J9.10 (D0)
D1: J8.6, J9.18 (D1)
GND: BT1.-, C1.2, C2.-, C3.2, C4.2, C5.2, C6.2, C7.2, C8.2, C13.2, C46.2, D1.A, D2.C, D4.A, D5.A, D8.A, D11.C, H5.1, J1.GND, J1.GND2 (GND), J2.3 (GND), J2.5 (GND), J2.9 (GND), J3.1, J4.2, J5.5, J6.3, J9.1 (GND), J9.7 (GND), J9.33 (GND), J9.36 (GND), J9.39 (GND), J9.45 (GND), J9.75 (GND), J10.1, J10.2, J10.3, J10.4, J10.5, J10.6, J11.CD1 (SHIELD), J11.GND, J11.GND1 (GND), J11.GND3 (GND), J12.3, J14.1, JP3.1, L1.2, R2.1, R3.1, R6.1, R9.1, R12.1, R14.2, R15.2, S1.1, S1.2 (1), S2.1, S2.2 (1), U1.1 (GND), U1.7 (GND), U2.1 (GND), U3.2 (INN), U3.4 (GND), U3.7 (EN_VREG), U3.9 (SI), U3.17 (GND_PAD), U5.4 (GND), U5.EP (GND)
I2C_SCL: J3.4, J9.14 (I2C_SCL), J14.4, R4.1, U1.4 (SCK/SCL), U2.3 (SCL)
I2C_SDA: J3.3, J9.12 (I2C_SDA), J14.3, R1.1, U1.3 (SDI/SDA), U2.2 (SDA)
I2S_SCK/PDM_CLK: J9.50 (AUD_CLK)
I2S_SD: J9.54 (AUD_IN)
I2S_WS/PDM_DAT: J9.52 (AUD_DATA)
INP: C8.1, L1.1, R6.2, U3.3 (INP)
LIGHTNING_INT: U3.10 (IRQ)
unnamed: MEAS.1, MEAS.3 (1), U5.1 (OUT)
unnamed: JP1.3, R4.2
unnamed: JP1.1, R1.2
unnamed: JP4.1, R11.2
unnamed: JP2.1, R20.2
unnamed: D2.A, R11.1
unnamed: J7.4, R12.2
unnamed: JP3.3, R7.1
unnamed: J7.3, R13.2
unnamed: J1.A5 (CC1), R2.2
unnamed: J1.B5 (CC2), R3.2
unnamed: J13.5, R14.1
unnamed: J13.4, R15.1
unnamed: BT1.+, D6.A, R8.1
unnamed: C7.1, U3.1 (AC_GND)
unnamed: D11.A, R20.1
unnamed: J13.3, R16.1
unnamed: J13.2, R17.1
PWM0: J8.3, J9.32 (PWM0)
PWM1: J8.4, J9.47 (PWM1)
RAIN: D3.A, D4.C, R13.1
RAIN2: J7.2
RAIN5: J7.5
RTC_3V: D6.C, D7.C, J9.72 (RTC_3V), R8.2
RX1: J6.2, J9.19 (RX1)
RX2: J9.20 (RX2), J12.2
SD_CLK: J9.60 (SDIO_CLK/SCK1), J11.SCLK (CLK/SCK)
SD_CMD: J9.62 (SDIO_CMD/MOSI1), J11.DI (CMD/MOSI)
SD_DAT0: J9.64 (SDIO_DATA0/MISO1), J11.DO (DAT0/MISO)
SD_DAT1: J9.66 (SDIO_DATA1), J11.RSV2 (DAT1/NC)
SD_DAT2: J9.68 (SDIO_DATA2), J11.RSV1 (DAT2/NC)
SD_DAT3: J9.70 (SDIO_DATA3), J11.CS (DAT3/CS)
SOIL_MOIST_SIG: J4.3
SPI_!CS!: J5.4, J9.55 (SPI_!CS!), R19.1, U3.8 (!CS)
SPI_CLK: J5.1, J9.57 (LED_CLK/SPI_SCK), U3.11 (SCL/I2CL)
SPI_MISO: J5.3, J9.61 (SPI_MISO), U3.12 (MISO)
SPI_MOSI: J5.2, J9.59 (LED_DAT/SPI_MOSI), U3.13 (MOSI/I2CD)
SWDCK: J2.4 (SWDCLK), J9.21 (SWDCK)
SWDIO: J2.2 (SWDIO), J9.23 (SWDIO)
TX1: J6.1, J9.17 (TX1)
TX2: J9.22 (TX2), J12.1
USBHOST_D+: J9.35 (USBHOST_D+)
USBHOST_D-: J9.37 (USBHOST_D-)
USB_D+: J1.A6 (D+), J1.B6 (D+), J9.3 (USB_D+)
USB_D-: J1.A7 (D-), J1.B7 (D-), J9.5 (USB_D-)
VIN: BYP.2, C1.1, C2.+, C13.1, F2.2, J9.9 (USB_VIN), JP2.2, R5.2, R10.2, U5.8 (IN)
VIN/3: J9.49 (BATT_VIN/3), R9.2, R10.1
V_USB: BYP.1, F2.1, J1.VBUS1 (VBUS), J1.VBUS2 (VBUS)
WDIR: D5.C, D9.A, R17.2, R18.1
WSPEED: D8.C, D10.A, R16.2

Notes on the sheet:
μSD
300uA Leakage
0.65uA Leakage 0.3V drop at 10mA
~20 minute charge time
1mAhr Capacity
This is the penny-in-the-fuse jumper. Close only if you know what you're doing.
JTAG
USB
GPIOs
Qwiic
RTC
Voltage Regulation
Universal MicroMod Connector
Priyanka Makin
WeatherStation-MM-Carrier
BME280 - Temp, Pressure, Humidity
UV Sensor
Soil Mositure Sensor Connector
Rain
Wind
LED's
Lightning Detector

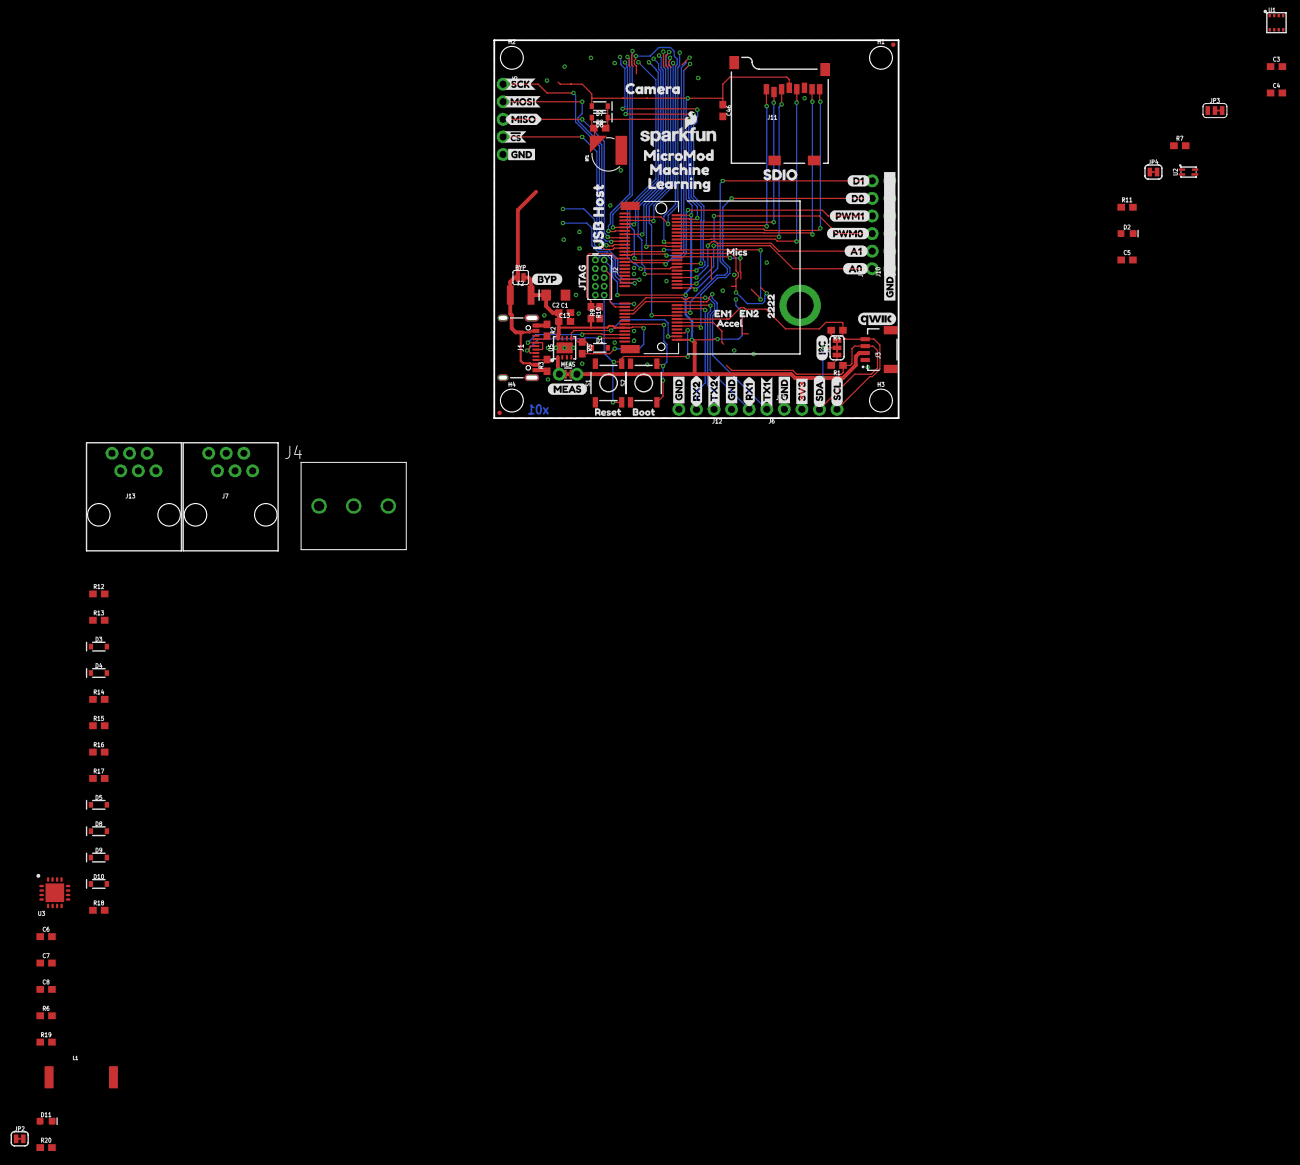
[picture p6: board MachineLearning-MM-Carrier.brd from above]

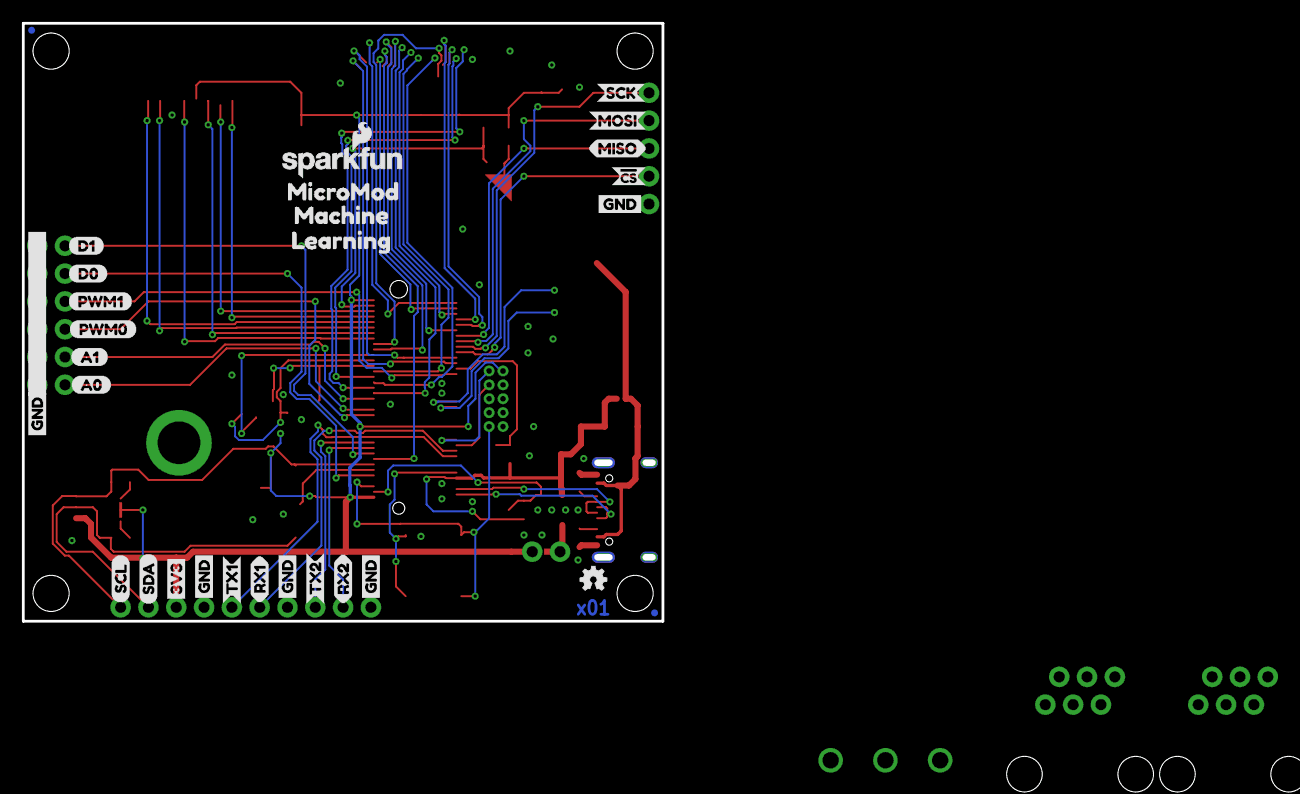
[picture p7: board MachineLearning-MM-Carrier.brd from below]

Board: 2 copper layers, 58.4 x 54.6 mm, 148 parts (29 on the bottom side), 59 nets.

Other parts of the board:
LOGO4: SFE_LOGO_NAME_FLAME.1_INCH; SFE_LOGO_NAME_FLAME_.1
U$1: ACCEL6
U$2: RESET3
U$3: CAMERA5
U$4, U$66: LEARNING3
U$5: MEAS
U$6, U$11, U$23, U$32, U$33, U$36, U$42, U$45, U$53, U$54: GND_P
U$7, U$50: MOSI_O
U$8, U$51: MISO_I
U$9, U$49: SCK_O
U$10, U$52: !CS_O
U$12, U$13: D13
U$14, U$16: D02
U$15, U$61: PWM10
U$17, U$30: RX25
U$18: JTAG_TO
U$19: BOOT2
U$20: USB_HOST0
U$21: SDIO1
U$22, U$65: MACHINE2
U$24, U$64: MICROMOD0
U$25, U$29: RX10
U$26: MICS0
U$27: BYP
U$28, U$56: TX24
U$31, U$41: TX13
U$34: EN13
U$35: EN24
U$37: I2C
U$38, U$46: 3V3_P
U$39, U$47: SDA_IO
U$40, U$48: SCL_IO
U$43, U$44: A00
U$55: 22229
U$57, U$58: A10
U$59, U$60: PWM01

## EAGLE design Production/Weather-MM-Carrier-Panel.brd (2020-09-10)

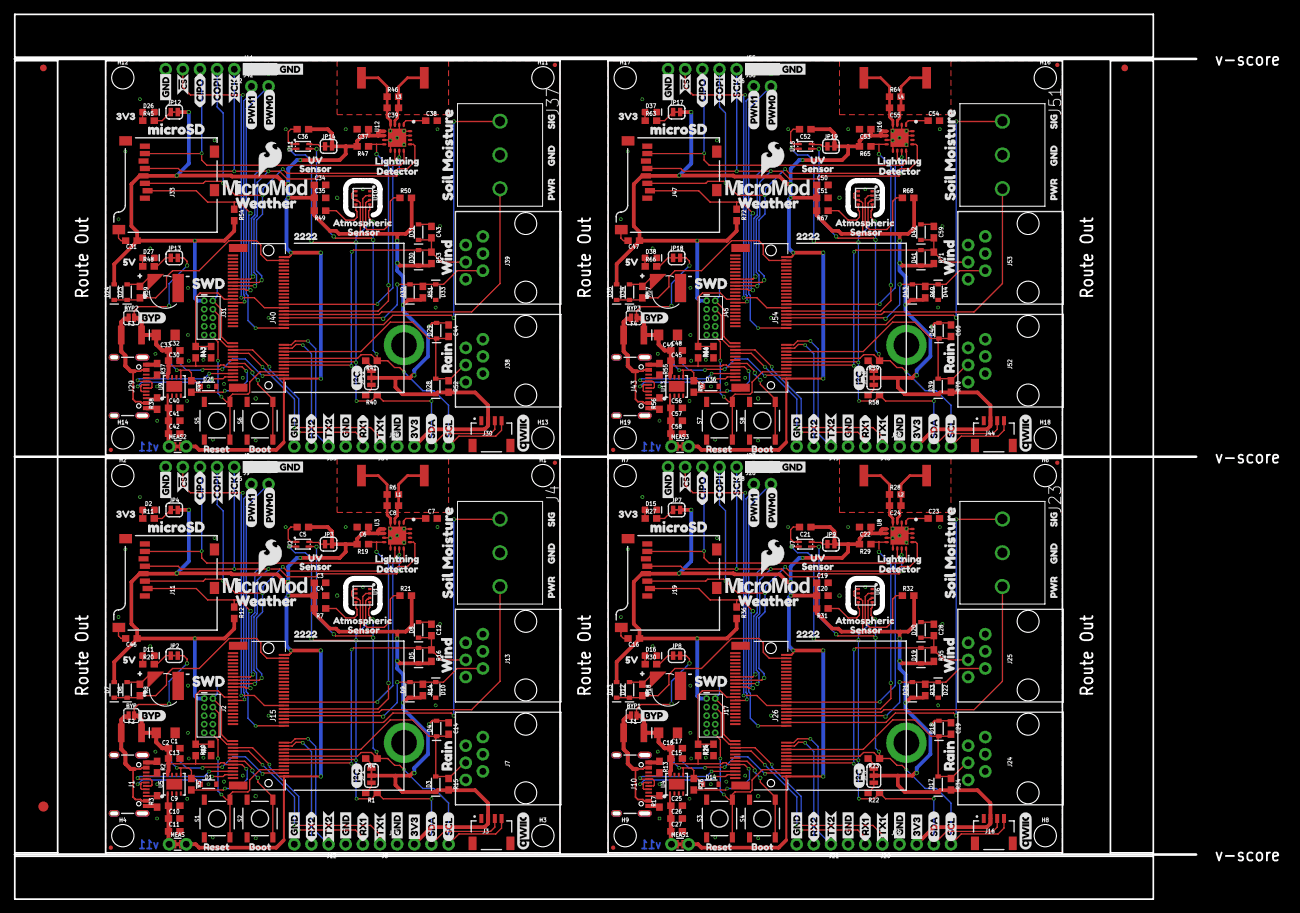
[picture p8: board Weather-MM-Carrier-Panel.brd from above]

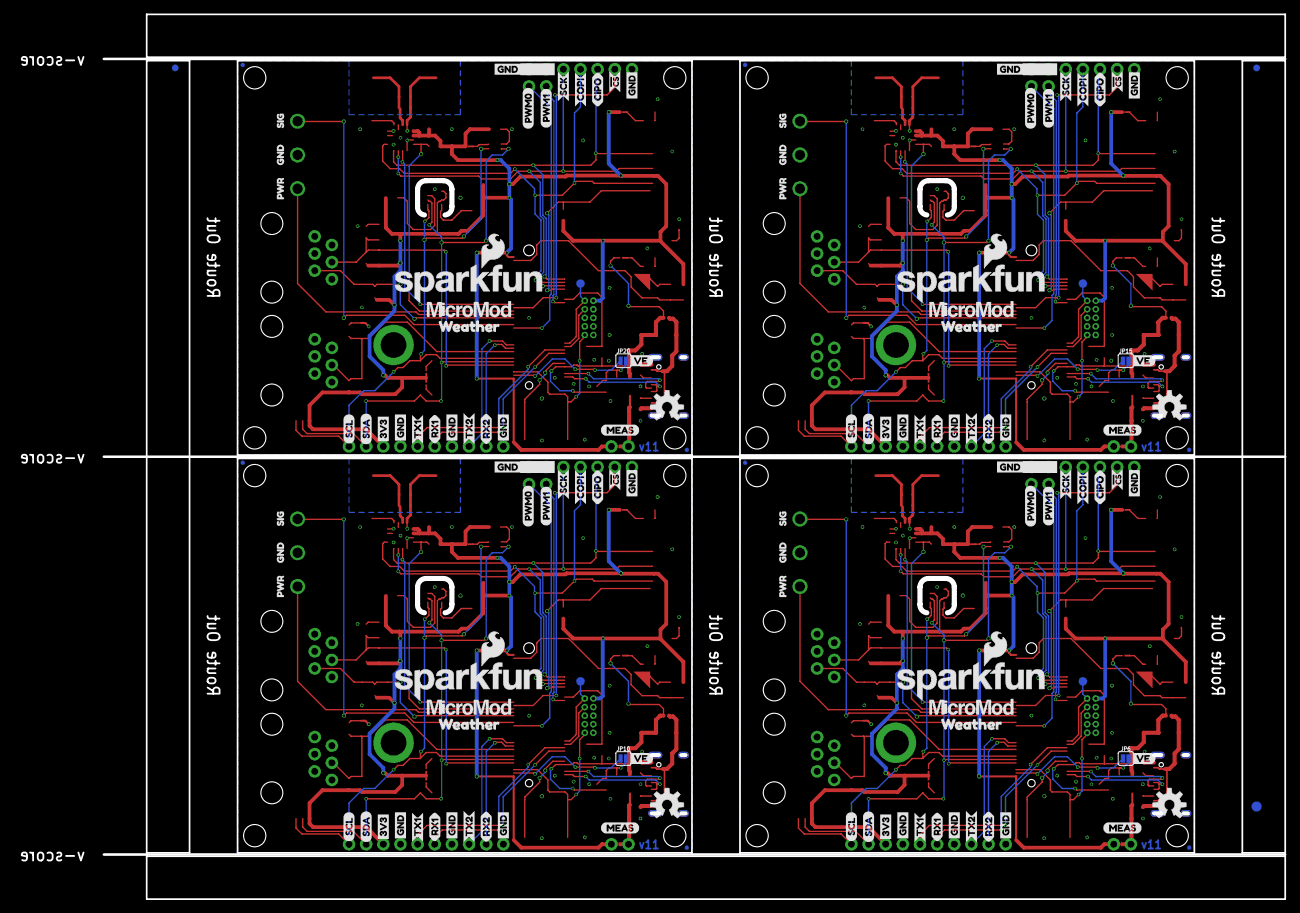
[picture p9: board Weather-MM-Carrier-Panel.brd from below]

Board: 2 copper layers, 175.0 x 131.1 mm, 630 parts (127 on the bottom side), 196 nets.

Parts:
BT1, BT2, BT3, BT4: ML414H; ML414H_IV01E
BYP, BYP1, BYP2, BYP3: JUMPER-SMT_2_NO_SILK; SMT-JUMPER_2_NO_SILK
C1, C3, C4, C5, C12, C14, C16, C17, C19, C20, C21, C28, C29, C31, C32, C34, C35, C36, C43, C44, C46, C47, C48, C50, C51, C52, C59, C60: 0.1uF; 0603
C2, C18, C33, C49: 10uF; EIA3216
C6, C10, C22, C26, C37, C41, C53, C57: 1.0uF; 0603
C7, C9, C23, C25, C38, C40, C54, C56: 10uF; 0603
C8, C24, C39, C55: 1nF; 0603
C11, C13, C15, C27, C30, C42, C45, C58: 0.22uF; 0603
D1, D14, D25, D36: 3.3V; SOD-323
D2, D11, D15, D16, D26, D27, D37, D38: RED; LED-0603
D3, D4, D5, D8, D9, D10, D17, D18, D19, D20, D21, D22, D28, D29, D30, D31, D32, D33, D39, D40, D41, D42, D43, D44: 250mA/100V; SOD-323
D6, D12, D23, D34: 3A/10V/280mV; SOD-323
D7, D13, D24, D35: 1A/23V/620mV; SOD-323
E$1, E$2, E$3, E$4: FIDUCIAL-1X2
E$5, E$6: FIDUCIAL-1.5X3
F1, F2, F3, F4: 6V/2A; 1210
FD1, FD2, FD3, FD4, FD5, FD6, FD7, FD8, FD9, FD10, FD11, FD12, FD13, FD14, FD15, FD16: FIDUCIALUFIDUCIAL; FIDUCIAL-MICRO
H1, H2, H3, H4, H6, H7, H8, H9, H11, H12, H13, H14, H16, H17, H18, H19: STAND-OFF
H5, H10, H15, H20: STAND-OFF-REFLOW2.5MM_TALL; STAND-OFF-REFLOW-M2.5
J1, J10, J29, J43: USB-C-16P-2LAYER-PADS
J2, J17, J31, J45: JTAG; 2X5-PTH-1.27MM
J3, J16, J30, J44: QWIIC_RIGHT_ANGLE; JST04_1MM_RA
J4, J23, J37, J51: LATCHTERMINAL-5MM-3
J5, J18, J32, J46: 1X05_NO_SILK
J6, J12, J20, J21, J34, J35, J48, J49: 1X03_NO_SILK
J7, J24, J38, J52: RJ11 - RAIN; RJ11-6
J8, J9, J27, J28, J41, J42, J55, J56: 1X02_NO_SILK
J11, J19, J33, J47: microSD; MICRO-SD-SOCKET
J13, J25, J39, J53: RJ11 - WIND; RJ11-6
J14, J22, J36, J50: 1X04_NO_SILK
J15, J26, J40, J54: MICROMOD-2222-C; M.2-CONNECTOR-E
JP1, JP5, JP11, JP16: SMT-JUMPER_3_2-NC_TRACE_SILK
JP2, JP8, JP13, JP18: VIN LED; SMT-JUMPER_2_NC_TRACE_SILK
JP3, JP9, JP14, JP19: UV; SMT-JUMPER_2_NC_TRACE_SILK
JP4, JP7, JP12, JP17: 3V3 LED; SMT-JUMPER_2_NC_TRACE_SILK
JP6, JP10, JP15, JP20: VE; SMT-JUMPER_2_NO_SILK
L1, L2, L3, L4: 100uH; MA5532-AE
LOGO1, LOGO6, LOGO9, LOGO12: SFE_LOGO_NAME_FLAME.2_INCH; SFE_LOGO_NAME_FLAME_.2
LOGO2, LOGO4, LOGO7, LOGO10: QWIIC_LOGO_CONNECTOR; QWIIC_5.5MM
LOGO3, LOGO5, LOGO8, LOGO11: OSHW-LOGOM; OSHW-LOGO-M
MEAS, MEAS1, MEAS2, MEAS3: COMBO-JUMPER_2_NC_TRACE
R1, R4, R22, R23, R40, R41, R58, R59: 2.2k; 0603
R2, R3, R13, R17, R37, R38, R55, R56: 5.1k; 0603
R5, R12, R19, R26, R29, R36, R44, R47, R54, R62, R65, R72: 100k; 0603
R6, R7, R9, R14, R21, R24, R28, R31, R32, R33, R42, R46, R49, R50, R51, R60, R64, R67, R68, R69: 10k; 0603
R8, R18, R39, R57: 3.3k; 0603
R10, R25, R43, R61: 20k; 0603
R11, R20, R27, R30, R45, R48, R63, R66: 1k; 0603
R15, R16, R34, R35, R52, R53, R70, R71: 43k; 0603
S1, S3, S5, S7: Reset; TACTILE_SWITCH_SMD_5.2MM
S2, S4, S6, S8: BOOT; TACTILE_SWITCH_SMD_5.2MM
TP1, TP2, TP3, TP4: TEST-POINT3X5; PAD.03X.05
U1, U6, U10, U14: BME280; LGA-8-2.5X2.5
U2, U7, U11, U15: VEML6075; VEML6075_A3OP
U3, U8, U12, U16: AS3935; 16LD_MLPQ
U4, U5, U9, U13: AP7361C-33FGEUDFN-8; UDFN-8
U$1, U$119, U$188, U$257: 3V31
U$2, U$26, U$139, U$208: RESET3
U$3, U$110, U$179, U$248: RAIN1
U$4, U$57, U$113, U$128, U$182, U$197, U$251, U$266: GND0
U$5, U$51, U$140, U$209: MEAS
U$6, U$11, U$23, U$32, U$33, U$36, U$42, U$45, U$53, U$54, U$74, U$75, U$79, U$80, U$82, U$86, U$89, U$90, U$96, U$99, U$143, U$144, U$148, U$149, U$151, U$155, U$158, U$159, U$165, U$168, U$212, U$213, U$217, U$218, U$220, U$224, U$227, U$228, U$234, U$237: GND_P
U$7, U$8, U$130, U$131, U$199, U$200, U$268, U$269: COPI0
U$9, U$49, U$72, U$94, U$141, U$163, U$210, U$232: SCK_O
U$10, U$52, U$73, U$95, U$142, U$164, U$211, U$233: !CS_O
U$12, U$24, U$114, U$127, U$183, U$196, U$252, U$265: PWR2
U$13, U$63, U$115, U$129, U$184, U$198, U$253, U$267: SIG1
U$14, U$135, U$204, U$273: BYP0
U$15, U$61, U$98, U$100, U$167, U$169, U$236, U$238: PWM10
U$16, U$58, U$116, U$122, U$185, U$191, U$254, U$260: WEATHER4
U$17, U$30, U$101, U$104, U$170, U$173, U$239, U$242: RX25
U$18, U$120, U$189, U$258: 5V0
U$19, U$76, U$145, U$214: BOOT2
U$20, U$123, U$192, U$261: ATMOSPHERIC0
U$21, U$138, U$207, U$276: VE0
U$22, U$107, U$176, U$245: LIGHTNING8
U$25, U$29, U$77, U$87, U$146, U$156, U$215, U$225: RX10
U$27, U$50, U$136, U$137, U$205, U$206, U$274, U$275: CIPO0
U$28, U$56, U$102, U$103, U$171, U$172, U$240, U$241: TX24
U$31, U$41, U$78, U$88, U$147, U$157, U$216, U$226: TX13
U$34, U$108, U$177, U$246: SENSOR7
U$35, U$117, U$186, U$255: MICROSD0
U$37, U$81, U$150, U$219: I2C
U$38, U$46, U$83, U$91, U$152, U$160, U$221, U$229: 3V3_P
U$39, U$47, U$84, U$92, U$153, U$161, U$222, U$230: SDA_IO
U$40, U$48, U$85, U$93, U$154, U$162, U$223, U$231: SCL_IO
U$43, U$118, U$187, U$256: SWD1
U$44, U$121, U$190, U$259: SFE_LOGO_FLAME_.2
U$55, U$97, U$166, U$235: 22229
U$59, U$60, U$105, U$106, U$174, U$175, U$243, U$244: PWM01
U$62, U$109, U$178, U$247: UV6
U$64, U$124, U$193, U$262: SENSOR1
U$65, U$111, U$180, U$249: SOIL_MOISTURE2
U$66, U$112, U$181, U$250: WIND0
U$67, U$68, U$125, U$126, U$194, U$195, U$263, U$264: MICROMOD_LOGO_.5
U$69, U$132, U$201, U$270: #0
U$70, U$133, U$202, U$271: #1
U$71, U$134, U$203, U$272: DETECTOR2

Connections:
3.3V: C3.1, C4.1, C5.1, C6.1, C46.1, D3.C, D5.C, D7.A, D9.C, J2.1, J3.2, J11.VCC, J14.2, J15.2, J15.74, JP1.2, JP3.2, JP4.2, MEAS.2, MEAS.4, R7.2, R12.2, R14.2, R15.2, R16.2, R19.2, R21.2, U1.6, U1.8, U3.5, U3.6
3.3V1: C16.1, C19.1, C20.1, C21.1, C22.1, D13.A, D17.C, D19.C, D21.C, J16.2, J17.1, J19.VCC, J22.2, J26.2, J26.74, JP5.2, JP7.2, JP9.2, MEAS1.2, MEAS1.4, R29.2, R31.2, R32.2, R33.2, R34.2, R35.2, R36.2, U6.6, U6.8, U8.5, U8.6
3.3V2: C31.1, C34.1, C35.1, C36.1, C37.1, D24.A, D28.C, D30.C, D32.C, J30.2, J31.1, J33.VCC, J36.2, J40.2, J40.74, JP11.2, JP12.2, JP14.2, MEAS2.2, MEAS2.4, R47.2, R49.2, R50.2, R51.2, R52.2, R53.2, R54.2, U10.6, U10.8, U12.5, U12.6
3.3V3: C47.1, C50.1, C51.1, C52.1, C53.1, D35.A, D39.C, D41.C, D43.C, J44.2, J45.1, J47.VCC, J50.2, J54.2, J54.74, JP16.2, JP17.2, JP19.2, MEAS3.2, MEAS3.4, R65.2, R67.2, R68.2, R69.2, R70.2, R71.2, R72.2, U14.6, U14.8, U16.5, U16.6
3.3V_EN: J15.4, JP6.1
3.3V_EN1: J26.4, JP10.1
3.3V_EN2: J40.4, JP15.1
3.3V_EN3: J54.4, JP20.1
!BOOT!: J15.11, S2.3, S2.4
!BOOT!1: J26.11, S4.3, S4.4
!BOOT!2: J40.11, S6.3, S6.4
!BOOT!3: J54.11, S8.3, S8.4
!RESET!: J2.10, J15.6, S1.3, S1.4
!RESET!1: J17.10, J26.6, S3.3, S3.4
!RESET!2: J31.10, J40.6, S5.3, S5.4
!RESET!3: J45.10, J54.6, S7.3, S7.4
GND: BT1.-, C1.2, C2.-, C3.2, C4.2, C5.2, C6.2, C7.2, C8.2, C9.2, C10.2, C11.2, C12.1, C13.2, C14.1, C46.2, D1.A, D2.C, D4.A, D8.A, D10.A, D11.C, H5.1, J1.GND, J1.GND2, J2.3, J2.5, J2.9, J3.1, J4.2, J5.5, J6.3, J7.4, J8.1, J8.2, J11.CD1, J11.GND, J11.GND1, J11.GND3, J12.3, J13.4, J13.5, J14.1, J15.1, J15.7, J15.33, J15.36, J15.39, J15.45, J15.75, L1.2, R2.1, R3.1, R6.1, R9.1, S1.1, S1.2, S2.1, S2.2, U1.1, U1.7, U2.1, U3.2, U3.4, U3.7, U3.9, U3.15, U3.16, U3.17, U5.4, U5.EP
GND1: BT2.-, C15.2, C16.2, C17.2, C18.-, C19.2, C20.2, C21.2, C22.2, C23.2, C24.2, C25.2, C26.2, C27.2, C28.1, C29.1, D14.A, D15.C, D16.C, D18.A, D20.A, D22.A, H10.1, J10.GND, J10.GND2, J16.1, J17.3, J17.5, J17.9, J18.5, J19.CD1, J19.GND, J19.GND1, J19.GND3, J20.3, J21.3, J22.1, J23.2, J24.4, J25.4, J25.5, J26.1, J26.7, J26.33, J26.36, J26.39, J26.45, J26.75, J27.1, J27.2, L2.2, R13.1, R17.1, R24.1, R28.1, S3.1, S3.2, S4.1, S4.2, U4.4, U4.EP, U6.1, U6.7, U7.1, U8.2, U8.4, U8.7, U8.9, U8.15, U8.16, U8.17
GND2: BT3.-, C30.2, C31.2, C32.2, C33.-, C34.2, C35.2, C36.2, C37.2, C38.2, C39.2, C40.2, C41.2, C42.2, C43.1, C44.1, D25.A, D26.C, D27.C, D29.A, D31.A, D33.A, H15.1, J29.GND, J29.GND2, J30.1, J31.3, J31.5, J31.9, J32.5, J33.CD1, J33.GND, J33.GND1, J33.GND3, J34.3, J35.3, J36.1, J37.2, J38.4, J39.4, J39.5, J40.1, J40.7, J40.33, J40.36, J40.39, J40.45, J40.75, J41.1, J41.2, L3.2, R37.1, R38.1, R42.1, R46.1, S5.1, S5.2, S6.1, S6.2, U9.4, U9.EP, U10.1, U10.7, U11.1, U12.2, U12.4, U12.7, U12.9, U12.15, U12.16, U12.17
GND3: BT4.-, C45.2, C47.2, C48.2, C49.-, C50.2, C51.2, C52.2, C53.2, C54.2, C55.2, C56.2, C57.2, C58.2, C59.1, C60.1, D36.A, D37.C, D38.C, D40.A, D42.A, D44.A, H20.1, J43.GND, J43.GND2, J44.1, J45.3, J45.5, J45.9, J46.5, J47.CD1, J47.GND, J47.GND1, J47.GND3, J48.3, J49.3, J50.1, J51.2, J52.4, J53.4, J53.5, J54.1, J54.7, J54.33, J54.36, J54.39, J54.45, J54.75, J55.1, J55.2, L4.2, R55.1, R56.1, R60.1, R64.1, S7.1, S7.2, S8.1, S8.2, U13.4, U13.EP, U14.1, U14.7, U15.1, U16.2, U16.4, U16.7, U16.9, U16.15, U16.16, U16.17
HEADER_!CS!: J5.4, J15.44
HEADER_!CS!1: J18.4, J26.44
HEADER_!CS!2: J32.4, J40.44
HEADER_!CS!3: J46.4, J54.44
I2C_SCL: J3.4, J14.4, J15.14, R4.1, U1.4, U2.3
I2C_SCL1: J16.4, J22.4, J26.14, R23.1, U6.4, U7.3
I2C_SCL2: J30.4, J36.4, J40.14, R41.1, U10.4, U11.3
I2C_SCL3: J44.4, J50.4, J54.14, R59.1, U14.4, U15.3
I2C_SDA: J3.3, J14.3, J15.12, R1.1, U1.3, U2.2
I2C_SDA1: J16.3, J22.3, J26.12, R22.1, U6.3, U7.2
I2C_SDA2: J30.3, J36.3, J40.12, R40.1, U10.3, U11.2
I2C_SDA3: J44.3, J50.3, J54.12, R58.1, U14.3, U15.2
INP: C8.1, L1.1, R6.2, U3.3
INP1: C24.1, L2.1, R28.2, U8.3
INP2: C39.1, L3.1, R46.2, U12.3
INP3: C55.1, L4.1, R64.2, U16.3
LIGHTNING_!CS!: J15.42, R19.1, U3.8
LIGHTNING_!CS!1: J26.42, R29.1, U8.8
LIGHTNING_!CS!2: J40.42, R47.1, U12.8
LIGHTNING_!CS!3: J54.42, R65.1, U16.8
LIGHTNING_INT: J15.46, U3.10
LIGHTNING_INT1: J26.46, U8.10
LIGHTNING_INT2: J40.46, U12.10
LIGHTNING_INT3: J54.46, U16.10
unnamed: C9.1, C10.1, C11.1, MEAS.1, MEAS.3, U5.1
unnamed: JP1.3, R4.2
unnamed: JP1.1, R1.2
unnamed: JP4.1, R11.2
unnamed: JP2.1, R20.2
unnamed: D2.A, R11.1
unnamed: JP3.1, U2.4
unnamed: R7.1, U1.5
unnamed: J10.A5, R13.2
unnamed: J1.A5, R2.2
unnamed: J1.B5, R3.2
unnamed: J10.B5, R17.2
unnamed: BT2.+, D12.A, R18.1
unnamed: BT1.+, D6.A, R8.1
unnamed: C7.1, U3.1
unnamed: D11.A, R20.1
unnamed: JP5.3, R23.2
unnamed: JP5.1, R22.2
unnamed: R21.1, U1.2
unnamed: C25.1, C26.1, C27.1, MEAS1.1, MEAS1.3, U4.1
unnamed: JP7.1, R27.2
unnamed: D15.A, R27.1
unnamed: C23.1, U8.1
unnamed: JP8.1, R30.2
unnamed: D16.A, R30.1
unnamed: R32.1, U6.2
unnamed: R31.1, U6.5
unnamed: JP9.1, U7.4
unnamed: J29.A5, R37.2
unnamed: J29.B5, R38.2
unnamed: BT3.+, D23.A, R39.1
unnamed: JP11.3, R41.2
unnamed: JP11.1, R40.2
unnamed: C40.1, C41.1, C42.1, MEAS2.1, MEAS2.3, U9.1
unnamed: JP12.1, R45.2
unnamed: D26.A, R45.1
unnamed: C38.1, U12.1
unnamed: JP13.1, R48.2
unnamed: D27.A, R48.1
unnamed: R50.1, U10.2
unnamed: R49.1, U10.5
unnamed: JP14.1, U11.4
unnamed: J43.A5, R55.2
unnamed: J43.B5, R56.2
unnamed: BT4.+, D34.A, R57.1
unnamed: JP16.3, R59.2
unnamed: JP16.1, R58.2
unnamed: C56.1, C57.1, C58.1, MEAS3.1, MEAS3.3, U13.1
unnamed: JP17.1, R63.2
unnamed: D37.A, R63.1
unnamed: C54.1, U16.1
unnamed: JP18.1, R66.2
unnamed: D38.A, R66.1
unnamed: R68.1, U14.2
unnamed: R67.1, U14.5
unnamed: JP19.1, U15.4
PWM0: J9.2, J15.32
PWM1: J9.1, J15.47
PWM2: J26.32, J28.2
PWM3: J26.47, J28.1
PWM4: J40.32, J42.2
PWM5: J40.47, J42.1
PWM6: J54.32, J56.2
PWM7: J54.47, J56.1
RAIN: C14.2, D3.A, D4.C, J7.3, J15.18, R15.1
RAIN1: C29.2, D17.A, D18.C, J24.3, J26.18, R34.1
RAIN2: C44.2, D28.A, D29.C, J38.3, J40.18, R52.1
RAIN3: C60.2, D39.A, D40.C, J52.3, J54.18, R70.1
RTC_3V: D6.C, D7.C, J15.72, R8.2
RTC_3V1: D12.C, D13.C, J26.72, R18.2
RTC_3V2: D23.C, D24.C, J40.72, R39.2
RTC_3V3: D34.C, D35.C, J54.72, R57.2
RX1: J6.2, J15.19
RX2: J12.2, J15.20
RX3: J20.2, J26.19
RX4: J21.2, J26.20
RX5: J34.2, J40.19
RX6: J35.2, J40.20
RX7: J48.2, J54.19
RX8: J49.2, J54.20
SD_!CS!: J11.CS/DAT3, J15.55, R12.1
SD_!CS!1: J19.CS/DAT3, J26.55, R36.1
SD_!CS!2: J33.CS/DAT3, J40.55, R54.1
SD_!CS!3: J47.CS/DAT3, J54.55, R72.1
SOIL_MOIST_PWR: J4.3, J15.40
SOIL_MOIST_PWR1: J23.3, J26.40
SOIL_MOIST_PWR2: J37.3, J40.40
SOIL_MOIST_PWR3: J51.3, J54.40
SOIL_MOIST_SIG: J4.1, J15.34
SOIL_MOIST_SIG1: J23.1, J26.34
SOIL_MOIST_SIG2: J37.1, J40.34
SOIL_MOIST_SIG3: J51.1, J54.34
SPI_CIPO: J5.3, J11.DO/DAT0, J15.61, U3.12
SPI_CIPO1: J18.3, J19.DO/DAT0, J26.61, U8.12
SPI_CIPO2: J32.3, J33.DO/DAT0, J40.61, U12.12
SPI_CIPO3: J46.3, J47.DO/DAT0, J54.61, U16.12
SPI_COPI: J5.2, J11.DI/CMD, J15.59, U3.13
SPI_COPI1: J18.2, J19.DI/CMD, J26.59, U8.13
SPI_COPI2: J32.2, J33.DI/CMD, J40.59, U12.13
SPI_COPI3: J46.2, J47.DI/CMD, J54.59, U16.13
SPI_SCK: J5.1, J11.SCLK, J15.57, U3.11
SPI_SCK1: J18.1, J19.SCLK, J26.57, U8.11
SPI_SCK2: J32.1, J33.SCLK, J40.57, U12.11
SPI_SCK3: J46.1, J47.SCLK, J54.57, U16.11
SWDCK: J2.4, J15.21
SWDCK1: J17.4, J26.21
SWDCK2: J31.4, J40.21
SWDCK3: J45.4, J54.21
SWDIO: J2.2, J15.23, TP1.P$1
SWDIO1: J17.2, J26.23, TP2.P$1
SWDIO2: J31.2, J40.23, TP3.P$1
SWDIO3: J45.2, J54.23, TP4.P$1
TX1: J6.1, J15.17
TX2: J12.1, J15.22
TX3: J20.1, J26.17
TX4: J21.1, J26.22
TX5: J34.1, J40.17
TX6: J35.1, J40.22
TX7: J48.1, J54.17
TX8: J49.1, J54.22
USB_D+: J1.A6, J1.B6, J15.3
USB_D+1: J10.A6, J10.B6, J26.3
USB_D+2: J29.A6, J29.B6, J40.3
USB_D+3: J43.A6, J43.B6, J54.3
USB_D-: J1.A7, J1.B7, J15.5
USB_D-1: J10.A7, J10.B7, J26.5
USB_D-2: J29.A7, J29.B7, J40.5
USB_D-3: J43.A7, J43.B7, J54.5
VIN: BYP.2, C1.1, C2.+, C13.1, F2.2, J15.9, JP2.2, R5.2, R10.2, U5.8
VIN1: BYP1.2, C15.1, C17.1, C18.+, F1.2, J26.9, JP8.2, R25.2, R26.2, U4.8
VIN2: BYP2.2, C30.1, C32.1, C33.+, F3.2, J40.9, JP13.2, R43.2, R44.2, U9.8
VIN3: BYP3.2, C45.1, C48.1, C49.+, F4.2, J54.9, JP18.2, R61.2, R62.2, U13.8
VIN/1: J26.49, R24.2, R25.1
VIN/2: J40.49, R42.2, R43.1
VIN/3: J15.49, R9.2, R10.1
VIN/4: J54.49, R60.2, R61.1
VREG_EN: D1.C, JP6.2, R5.1, U5.5
VREG_EN1: D14.C, JP10.2, R26.1, U4.5
VREG_EN2: D25.C, JP15.2, R44.1, U9.5
VREG_EN3: D36.C, JP20.2, R62.1, U13.5
V_USB: BYP.1, F2.1, J1.VBUS1, J1.VBUS2
V_USB1: BYP1.1, F1.1, J10.VBUS1, J10.VBUS2
V_USB2: BYP2.1, F3.1, J29.VBUS1, J29.VBUS2
V_USB3: BYP3.1, F4.1, J43.VBUS1, J43.VBUS2
WDIR: D9.A, D10.C, J13.2, J15.38, R14.1
WDIR1: D21.A, D22.C, J25.2, J26.38, R33.1
WDIR2: D32.A, D33.C, J39.2, J40.38, R51.1
WDIR3: D43.A, D44.C, J53.2, J54.38, R69.1
WSPEED: C12.2, D5.A, D8.C, J13.3, J15.10, R16.1
WSPEED1: C28.2, D19.A, D20.C, J25.3, J26.10, R35.1
WSPEED2: C43.2, D30.A, D31.C, J39.3, J40.10, R53.1
WSPEED3: C59.2, D41.A, D42.C, J53.3, J54.10, R71.1

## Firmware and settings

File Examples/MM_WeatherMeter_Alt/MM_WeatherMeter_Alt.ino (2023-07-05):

/*
  Weather Shield Example
  By: Nathan Seidle
  SparkFun Electronics
  Date: November 16th, 2013
  License: MIT

  Much of this is based on Mike Grusin's USB Weather Board code: https://www.sparkfun.com/products/10586

  This is a more advanced example of how to utilize every aspect of the weather shield. See the basic
  example if you're just getting started.

  This code reads all the various sensors (wind speed, direction, rain gauge, humidity, pressure, light, batt_lvl)
  and reports it over the serial comm port.

  Measurements are reported once a second but wind speed and rain gauge are tied to interrupts that are
  calculated at each report.


  Updated by Joel Bartlett
  03/02/2017
  Removed HTU21D code and replaced with Si7021

*/

#include <Wire.h> //I2C needed for sensors

//Hardware pin definitions
//-=-=-=-=-=-=-=-=-=-=-=-=-=-=-=-=-=-=-=-=-=-=-=-=-=-=-=-=
#if defined(ESP_PLATFORM)
int D0 = 23;
int A1 = 35;
int D1 = 27;
#elif defined(ARDUINO_ARCH_SAMD)
int D0 = 0;
int D1 = 1;
#endif

int WSPEED = D0;  //Digital I/O pin for wind speed
int WDIR = A1;  //Analog pin for wind direction
int RAIN = D1;  //Digital I/O pin for rain fall
//-=-=-=-=-=-=-=-=-=-=-=-=-=-=-=-=-=-=-=-=-=-=-=-=-=-=-=-=

//Global Variables
//-=-=-=-=-=-=-=-=-=-=-=-=-=-=-=-=-=-=-=-=-=-=-=-=-=-=-=-=
long lastSecond; //The millis counter to see when a second rolls by
byte seconds; //When it hits 60, increase the current minute
byte seconds_2m; //Keeps track of the "wind speed/dir avg" over last 2 minutes array of data
byte minutes; //Keeps track of where we are in various arrays of data
byte minutes_10m; //Keeps track of where we are in wind gust/dir over last 10 minutes array of data

long lastWindCheck = 0;
volatile long lastWindIRQ = 0;
volatile byte windClicks = 0;

//We need to keep track of the following variables:
//Wind speed/dir each update (no storage)
//Wind gust/dir over the day (no storage)
//Wind speed/dir, avg over 2 minutes (store 1 per second)
//Wind gust/dir over last 10 minutes (store 1 per minute)
//Rain over the past hour (store 1 per minute)
//Total rain over date (store one per day)

byte windspdavg[120]; //120 bytes to keep track of 2 minute average

#define WIND_DIR_AVG_SIZE 120
int winddiravg[WIND_DIR_AVG_SIZE]; //120 ints to keep track of 2 minute average
float windgust_10m[10]; //10 floats to keep track of 10 minute max
int windgustdirection_10m[10]; //10 ints to keep track of 10 minute max
volatile float rainHour[60]; //60 floating numbers to keep track of 60 minutes of rain

//These are all the weather values that wunderground expects:
int winddir = 0; // [0-360 instantaneous wind direction]
float windspeedmph = 0; // [mph instantaneous wind speed]
float windgustmph = 0; // [mph current wind gust, using software specific time period]
int windgustdir = 0; // [0-360 using software specific time period]
float windspdmph_avg2m = 0; // [mph 2 minute average wind speed mph]
int winddir_avg2m = 0; // [0-360 2 minute average wind direction]
float windgustmph_10m = 0; // [mph past 10 minutes wind gust mph ]
int windgustdir_10m = 0; // [0-360 past 10 minutes wind gust direction]
float rainin = 0; // [rain inches over the past hour)] -- the accumulated rainfall in the past 60 min
volatile float dailyrainin = 0; // [rain inches so far today in local time]

// volatiles are subject to modification by IRQs
volatile unsigned long raintime, rainlast, raininterval, rain;

//-=-=-=-=-=-=-=-=-=-=-=-=-=-=-=-=-=-=-=-=-=-=-=-=-=-=-=-=

//Interrupt routines (these are called by the hardware interrupts, not by the main code)
//-=-=-=-=-=-=-=-=-=-=-=-=-=-=-=-=-=-=-=-=-=-=-=-=-=-=-=-=
void rainIRQ()
// Count rain gauge bucket tips as they occur
// Activated by the magnet and reed switch in the rain gauge, attached to input D2
{
  raintime = millis(); // grab current time
  raininterval = raintime - rainlast; // calculate interval between this and last event

  if (raininterval > 10) // ignore switch-bounce glitches less than 10mS after initial edge
  {
    dailyrainin += 0.011; //Each dump is 0.011" of water
    rainHour[minutes] += 0.011; //Increase this minute's amount of rain

    rainlast = raintime; // set up for next event
  }
}

void wspeedIRQ()
// Activated by the magnet in the anemometer (2 ticks per rotation), attached to input D3
{
  if (millis() - lastWindIRQ > 10) // Ignore switch-bounce glitches less than 10ms (142MPH max reading) after the reed switch closes
  {
    lastWindIRQ = millis(); //Grab the current time
    windClicks++; //There is 1.492MPH for each click per second.
  }
}

void setup()
{
  Serial.begin(115200);
  Serial.println("Weather Shield Example");

  pinMode(WSPEED, INPUT_PULLUP); // input from wind meters windspeed sensor
  pinMode(RAIN, INPUT_PULLUP); // input from wind meters rain gauge sensor

  seconds = 0;
  lastSecond = millis();

  // attach external interrupt pins to IRQ functions
  attachInterrupt(RAIN, rainIRQ, FALLING);
  attachInterrupt(WSPEED, wspeedIRQ, FALLING);

  // turn on interrupts
  interrupts();

  Serial.println("Weather Shield online!");

}

void loop()
{
  //Keep track of which minute it is
  if (millis() - lastSecond >= 1000)
  {
    digitalWrite(LED_BUILTIN, HIGH); //Blink stat LED

    lastSecond += 1000;

    //Take a speed and direction reading every second for 2 minute average
    if (++seconds_2m > 119) seconds_2m = 0;

    //Calc the wind speed and direction every second for 120 second to get 2 minute average
    float currentSpeed = get_wind_speed();
    windspeedmph = currentSpeed;//update global variable for windspeed when using the printWeather() function
    //float currentSpeed = random(5); //For testing
    int currentDirection = get_wind_direction();
    windspdavg[seconds_2m] = (int)currentSpeed;
    winddiravg[seconds_2m] = currentDirection;
    //if(seconds_2m % 10 == 0) displayArrays(); //For testing

    //Check to see if this is a gust for the minute
    if (currentSpeed > windgust_10m[minutes_10m])
    {
      windgust_10m[minutes_10m] = currentSpeed;
      windgustdirection_10m[minutes_10m] = currentDirection;
    }

    //Check to see if this is a gust for the day
    if (currentSpeed > windgustmph)
    {
      windgustmph = currentSpeed;
      windgustdir = currentDirection;
    }

    if (++seconds > 59)
    {
      seconds = 0;

      if (++minutes > 59) minutes = 0;
      if (++minutes_10m > 9) minutes_10m = 0;

      rainHour[minutes] = 0; //Zero out this minute's rainfall amount
      windgust_10m[minutes_10m] = 0; //Zero out this minute's gust
    }

    //Report all readings every second
    printWeather();

    digitalWrite(LED_BUILTIN, LOW); //Turn off stat LED
  }

  delay(100);
}

//Calculates each of the variables that wunderground is expecting
void calcWeather()
{
  //Calc winddir
  winddir = get_wind_direction();

  //Calc windspeed
  //windspeedmph = get_wind_speed(); //This is calculated in the main loop on line 185

  //Calc windgustmph
  //Calc windgustdir
  //These are calculated in the main loop

  //Calc windspdmph_avg2m
  float temp = 0;
  for (int i = 0 ; i < 120 ; i++)
    temp += windspdavg[i];
  temp /= 120.0;
  windspdmph_avg2m = temp;

  //Calc winddir_avg2m, Wind Direction
  //You can't just take the average. Google "mean of circular quantities" for more info
  //We will use the Mitsuta method because it doesn't require trig functions
  //And because it sounds cool.
  //Based on: http://abelian.org/vlf/bearings.html
  //Based on: http://stackoverflow.com/questions/1813483/averaging-angles-again
  long sum = winddiravg[0];
  int D = winddiravg[0];
  for (int i = 1 ; i < WIND_DIR_AVG_SIZE ; i++)
  {
    int delta = winddiravg[i] - D;

    if (delta < -180)
      D += delta + 360;
    else if (delta > 180)
      D += delta - 360;
    else
      D += delta;

    sum += D;
  }
  winddir_avg2m = sum / WIND_DIR_AVG_SIZE;
  if (winddir_avg2m >= 360) winddir_avg2m -= 360;
  if (winddir_avg2m < 0) winddir_avg2m += 360;

  //Calc windgustmph_10m
  //Calc windgustdir_10m
  //Find the largest windgust in the last 10 minutes
  windgustmph_10m = 0;
  windgustdir_10m = 0;
  //Step through the 10 minutes
  for (int i = 0; i < 10 ; i++)
  {
    if (windgust_10m[i] > windgustmph_10m)
    {
      windgustmph_10m = windgust_10m[i];
      windgustdir_10m = windgustdirection_10m[i];
    }
  }

  //Total rainfall for the day is calculated within the interrupt
  //Calculate amount of rainfall for the last 60 minutes
  rainin = 0;
  for (int i = 0 ; i < 60 ; i++)
    rainin += rainHour[i];
}

//Returns the instataneous wind speed
float get_wind_speed()
{
  float deltaTime = millis() - lastWindCheck; //750ms

  deltaTime /= 1000.0; //Covert to seconds

  float windSpeed = (float)windClicks / deltaTime; //3 / 0.750s = 4

  windClicks = 0; //Reset and start watching for new wind
  lastWindCheck = millis();

  windSpeed *= 1.492; //4 * 1.492 = 5.968MPH

  /* Serial.println();
    Serial.print("Windspeed:");
    Serial.println(windSpeed);*/

  return (windSpeed);
}

//Read the wind direction sensor, return heading in degrees
int get_wind_direction()
{
  unsigned int adc;

  adc = analogRead(WDIR); // get the current reading from the sensor

  // The following table is ADC readings for the wind direction sensor output, sorted from low to high.
  // Each threshold is the midpoint between adjacent headings. The output is degrees for that ADC reading.
  // Note that these are not in compass degree order! See Weather Meters datasheet for more information.

  if (adc < 380) return (113);
  if (adc < 393) return (68);
  if (adc < 414) return (90);
  if (adc < 456) return (158);
  if (adc < 508) return (135);
  if (adc < 551) return (203);
  if (adc < 615) return (180);
  if (adc < 680) return (23);
  if (adc < 746) return (45);
  if (adc < 801) return (248);
  if (adc < 833) return (225);
  if (adc < 878) return (338);
  if (adc < 913) return (0);
  if (adc < 940) return (293);
  if (adc < 967) return (315);
  if (adc < 990) return (270);
  return (-1); // error, disconnected?
}


//Prints the various variables directly to the port
//I don't like the way this function is written but Arduino doesn't support floats under sprintf
void printWeather()
{
  calcWeather(); //Go calc all the various sensors

  Serial.println();
  Serial.print("$,winddir=");
  Serial.print(winddir);
  Serial.print(",windspeedmph=");
  Serial.print(windspeedmph, 1);
  Serial.print(",windgustmph=");
  Serial.print(windgustmph, 1);
  Serial.print(",windgustdir=");
  Serial.print(windgustdir);
  Serial.print(",windspdmph_avg2m=");
  Serial.print(windspdmph_avg2m, 1);
  Serial.print(",winddir_avg2m=");
  Serial.print(winddir_avg2m);
  Serial.print(",windgustmph_10m=");
  Serial.print(windgustmph_10m, 1);
  Serial.print(",windgustdir_10m=");
  Serial.print(windgustdir_10m);
  Serial.print(",rainin=");
  Serial.print(rainin, 2);
  Serial.print(",dailyrainin=");
  Serial.print(dailyrainin, 2);
  Serial.print(",");
  Serial.println("#");
}

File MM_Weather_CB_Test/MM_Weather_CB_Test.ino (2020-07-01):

/*
  MicroMod Weather Carrier Board Test

  To Be Tested:
  DONE: Stat led
  DONE: BME280 - temp, pressure, humidity (I2C)
  DONE: VEML6075 - UV sensor (I2C)
  AS3935 - lightning detector (SPI)
  DONE: Soil moisture connector
  DONE: Wind Meter
  DONE: Rain Meter
  DONE: uSD card
  Other
    PWM0/1 -- 1 doesn't work
    DONE: Qwiic Connector
    TX/RX 1/2 -- tested in separate sketch, need diff PB to test TX/RX2
    VIN/3 -- doesn't work
*/

#include <Wire.h>
#include <SPI.h>
#include <SD.h>
#include "SparkFunBME280.h"
#include <SparkFun_VEML6075_Arduino_Library.h>
#include <SparkFun_Alphanumeric_Display.h>  

BME280 tempSensor;
VEML6075 uv;
Sd2Card card;
SdVolume volume;
HT16K33 display;  //For testing the qwiic connector

int STAT_LED = 19;
int moist_val = 0;  //Variable for storing moisture value
int soilPin = A32;  //Pin number that measures analog moisture signal
int soilPower = A16;  //Pin number that will power the soil moisture sensor

int WSPEED = 1; //Digital I/O pin for wind speed
int WDIR = A35; //Analog pin for wind direction
int RAIN = 2;   //Digital I/O pin for rain fall
volatile bool rain_flag = false;
volatile bool wind_flag = false;

const int SD_chipSelect = 23;
//const int SD_chipSelect = CS; //Chip select pin for SD card
const int PIN_PWM0 = 44;
const int PIN_PWM1 = 45;


//TODO: change IRQ's to return flags, variables need to be declared volatile
//Function is called every time the rain bucket tips
void rainIRQ()
{
  rain_flag = true;
}

//Function is called when the magnet in the anemometer is activated
void wspeedIRQ()
{
  wind_flag = true;
}

void setup() {
  Serial.begin(115200);
  Serial.println("MicroMod Weather Carrier Board Test");
  Serial.println();

  Wire.begin();

  if (tempSensor.beginI2C() == false) { //Begin communication over I2C
    Serial.println("BME280 did not respond.");
    while(1); //Freeze
  }
  if (uv.begin() == false) {
    Serial.println("VEML6075 did not respond.");
    while(1);
  }
  
  pinMode(STAT_LED, OUTPUT);
  pinMode(soilPower, OUTPUT);
  digitalWrite(soilPower, LOW);

  //Initialization for weather meter
  pinMode(WSPEED, INPUT_PULLUP);  //Input from wind meters windspeed sensor
  pinMode(RAIN, INPUT_PULLUP);    //Input from wind meters rain gauge sensor
  //attach external interrupt pins to IRQ functions
  attachInterrupt(digitalPinToInterrupt(RAIN), rainIRQ, FALLING);
  attachInterrupt(digitalPinToInterrupt(WSPEED), wspeedIRQ, FALLING);
  //turn on interrupts
  interrupts();

  testSD();
  testRemainingPeripherals();
}

// the loop function runs over and over again forever
void loop() {
  Serial.println();
  Serial.println("BME280 Check");
  Serial.print("Temperature: ");
  Serial.println(tempSensor.readTempF(), 2);
  Serial.print("Humidity: ");
  Serial.println(tempSensor.readFloatHumidity(), 0);
  Serial.print("Pressure: ");
  Serial.println(tempSensor.readFloatPressure(), 0);
  Serial.print("Altitude: ");
  Serial.println(tempSensor.readFloatAltitudeFeet(), 1);
  Serial.println();

  Serial.println("VEML6075 Check");
  Serial.println(String(uv.uva()) + ", " + String(uv.uvb()) + ", "+ String(uv.index()));
  Serial.println();

  Serial.println("Soil Moisture Sensor Check");
  Serial.print("Soil Moisture = ");
  Serial.println(readSoil());

  Serial.println("Weather Meter Wind Direction Check");
  Serial.print("Wind direction: ");
  Serial.print(get_wind_direction());
  Serial.println(" degrees");
  //Check interrupt flags
  if (rain_flag == true){
    Serial.println("RRRRRAAAAIIIINNN!!!");
    rain_flag = false;
  }
  if (wind_flag == true){
    Serial.println("Wind click!");
    wind_flag = false;
  }
  
  digitalWrite(STAT_LED, HIGH);   // turn the LED on (HIGH is the voltage level)
  delay(1000);                       // wait for a second
  digitalWrite(STAT_LED, LOW);    // turn the LED off by making the voltage LOW
  delay(1000);                       // wait for a second

  delay(2000);
}

void testSD() {
  //SD Card test
  Serial.println("Initializing SD card...");
  
  if (!card.init(SPI_HALF_SPEED, SD_chipSelect)) {
    Serial.println("initialization failed. Things to check:");
    Serial.println("* is a card inserted?");
    Serial.println("* is your wiring correc?");
    Serial.println("* did you change the chipSelect pin to match your module?");
    while(1);
  } else {
    Serial.println("Wiring is correct and a card is present.");
  }

  //print the type of card
  Serial.println();
  Serial.print("Card type:          ");
  switch (card.type()) {
    case SD_CARD_TYPE_SD1:
      Serial.println("SD1");
      break;
    case SD_CARD_TYPE_SD2:
      Serial.println("SD2");
      break;
    case SD_CARD_TYPE_SDHC:
      Serial.println("SDHC");
      break;
    default:
      Serial.println("Unknown");
  }

  if (!volume.init(card)) {
    Serial.println("Could not find FAT16/FAT32 partition. \nMake sure you've formatted the card");
    while(1);
  }
  
  //print the type and size of hte first FAT-type volume
  uint32_t volumesize;
  Serial.print("Volume type is:     FAT");
  Serial.println(volume.fatType(), DEC);

  volumesize = volume.blocksPerCluster();
  volumesize *= volume.clusterCount();
  volumesize /= 2;
  volumesize /= 1024;
  Serial.print("Volume size (Gb): ");
  Serial.println((float)volumesize / 1024.0);
}

int readSoil() {
  //Power Senor
  digitalWrite(soilPower, HIGH);
  delay(10);
  moist_val = analogRead(soilPin);  //Read the SIG value from sensor
  digitalWrite(soilPower, LOW); //Turn the sensor off
  return moist_val; //Return current moisture value
}

int get_wind_direction()
{
  unsigned int adc;
  adc = analogRead(WDIR); //get the current readings from the sensor

  if (adc < 380) return (113);
  if (adc < 393) return (68);
  if (adc < 414) return (90);
  if (adc < 456) return (158);
  if (adc < 508) return (135);
  if (adc < 551) return (203);
  if (adc < 615) return (180);
  if (adc < 680) return (23);
  if (adc < 746) return (45);
  if (adc < 801) return (248);
  if (adc < 833) return (225);
  if (adc < 878) return (338);
  if (adc < 913) return (0);
  if (adc < 940) return (293);
  if (adc < 967) return (315);
  if (adc < 990) return (270);
  return (-1);
}

void testRemainingPeripherals() {
  Serial.println();
  //Test Qwiic Connector
  Serial.println("Test Qwiic Connector");
  if (display.begin() == false)
  {
    Serial.println("Alphanumeric did not acknowledge! Freezing.");
    while(1);
  }
  Serial.println("Alphanumeric acknowledged.");
  display.print("Milk");
  Serial.println();
  
  //Test PWM0/1
  Serial.println("Test PWM0/1. Use multimeter to verify.");
  analogWrite(PIN_PWM0, 125);
//  analogWrite(PIN_PWM1, 125); //TODO: this one doesn't work
  Serial.println();

  //Test VIN/3
  Serial.println("VIN/3 Test");
  analogReadResolution(14);
  int temp = analogRead(31);
//  temp = (temp * 3 * 2)/16384;
  Serial.println(temp);
}

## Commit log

2020-04-20 Initial commit
    Copy of machine learning carrier board eagle files
    [MachineLearning-MM-Carrier.brd, MachineLearning-MM-Carrier.sch]
2020-04-20 Took out unnecessary blocks
    From copy of machine learning carrier board
2020-04-20 Added BME280 block
    [MachineLearning-MM-Carrier.sch]
2020-04-20 Added UV (VEML6075) sensor block
2020-04-20 Added connector for soil moisture sensor
    [MachineLearning-MM-Carrier.brd, MachineLearning-MM-Carrier.sch]
2020-04-22 Added RJ11 connectors for weather station add-on
    [MachineLearning-MM-Carrier.brd, MachineLearning-MM-Carrier.sch]
2020-04-22 Added lightning detector block
    [MachineLearning-MM-Carrier.brd, MachineLearning-MM-Carrier.sch]
2020-04-22 Fix net names
    Also renamed the sch/brd files to the right name
    [WeatherStation-MM-Carrier.brd, WeatherStation-MM-Carrier.sch]
2020-04-27 Final schematic changes from review and Nate's notes
    [WeatherStation-MM-Carrier.brd, WeatherStation-MM-Carrier.sch]
2020-04-29 Preliminary board layout
    [WeatherStation-MM-Carrier.brd, WeatherStation-MM-Carrier.sch]
2020-04-29 Moved power LEDs
    [WeatherStation-MM-Carrier.brd]
2020-04-29 Revised hardware layout
    [WeatherStation-MM-Carrier.brd, WeatherStation-MM-Carrier.sch]
2020-04-29 Updated labels, condensed layout
    [WeatherStation-MM-Carrier.brd]
2020-05-04 Change MM pinout to new SPI standard
    [WeatherStation-MM-Carrier.brd, WeatherStation-MM-Carrier.sch]
2020-05-05 Working on routing
    [WeatherStation-MM-Carrier.brd]
2020-05-06 Routing finished for now
    [WeatherStation-MM-Carrier.brd]
2020-05-06 Added silkscreen
    [WeatherStation-MM-Carrier.brd, WeatherStation-MM-Carrier.sch]
2020-05-08 Removed ground plane from underneath lightning sensor coil
    [WeatherStation-MM-Carrier.brd]
2020-05-12 Review changes
    [WeatherStation-MM-Carrier.sch]
2020-05-12 Board review changes
    [WeatherStation-MM-Carrier.brd, WeatherStation-MM-Carrier.sch]
2020-05-14 Review notes
    [WeatherStation-MM-Carrier.brd, WeatherStation-MM-Carrier.sch]
2020-05-14 Revision changes
    [WeatherStation-MM-Carrier.brd, WeatherStation-MM-Carrier.sch]
2020-05-15 Production files
    [WeatherStation-MM-Carrier-Panel.brd]
2020-05-29 Added PROD_ID for latching terminal
    [WeatherStation-MM-Carrier.brd, WeatherStation-MM-Carrier.sch]
2020-06-01 Implementing some changes from design check list
    [WeatherStation-MM-Carrier.brd, WeatherStation-MM-Carrier.sch]
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2020-06-25 Added jumper on 3.3V_EN
    [WeatherStation-MM-Carrier.brd, WeatherStation-MM-Carrier.sch]
2020-07-02 Update weather meter circuitry
    [WeatherStation-MM-Carrier.brd, WeatherStation-MM-Carrier.sch]
2020-07-06 Changes from Nate
    Rotate soil moisture connector pins
    MOSI/MISO --> COPI, POCI
    Rotate LEDs
    +/- silk on batt
    Changed labels on jumpers
    [WeatherStation-MM-Carrier.brd, WeatherStation-MM-Carrier.sch]
2020-07-07 Added serial test. Updated brd to pass design rules
    [WeatherStation-MM-Carrier.brd]
2020-07-08 Changed "POCI" label to "CIPO"
    [WeatherStation-MM-Carrier.brd]
2020-07-08 Impelemented design review changes
    [WeatherStation-MM-Carrier.brd, WeatherStation-MM-Carrier.sch]
2020-07-13 Removed VIN/3 jumper
    [WeatherStation-MM-Carrier.brd, WeatherStation-MM-Carrier.sch]
2020-07-14 Moved silkscreen
    [WeatherStation-MM-Carrier.brd, WeatherStation-MM-Carrier.sch]
2020-07-14 QC Double check changes
    Added SWDIO test point, notes on VE jumper, measurements for standoffs, double check sparkle BOM, and DRC
    [WeatherStation-MM-Carrier.brd, WeatherStation-MM-Carrier.sch]
2020-07-14 Changed VE jumper silk
    [WeatherStation-MM-Carrier.brd]
2020-07-14 Fixed wire stubs?
    [WeatherStation-MM-Carrier.brd]
2020-07-15 Added pullup resistor on CS line for SD card
    [WeatherStation-MM-Carrier.brd, WeatherStation-MM-Carrier.sch]
2020-07-16 Update WeatherStation-MM-Carrier.brd
    Approved errors on DRC
    [WeatherStation-MM-Carrier.brd]
2020-07-16 Moved 3.3V LED circuit to match 5V. Re-panelized and re-cammed
    [WeatherStation-MM-Carrier-Panel.GBL, WeatherStation-MM-Carrier-Panel.GBO, WeatherStation-MM-Carrier-Panel.GBP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]
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2020-08-11 Changed lightning CS from 10k to 100k (for ESP bootloading)
    [WeatherStation-MM-Carrier.brd, WeatherStation-MM-Carrier.sch]
2020-08-17 Fixing MM artemis pins
    [MM_LightningDetector_Test.ino, MM_SoilSensorConnector_Test.ino, MM_WeatherMeter_Test.ino]
2020-08-25 Updated M.2 connector with increased tCream layer. Regenerated production files
    [WeatherStation-MM-Carrier-Panel.brd, WeatherStation-MM-Carrier.brd, WeatherStation-MM-Carrier.sch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]
2020-08-25 Renamed eagle project
    FromWeatherStation-MM-Carrier to Weather-MM-Carrier
    [Weather-MM-Carrier-Panel.GBL, Weather-MM-Carrier-Panel.GBO, Weather-MM-Carrier-Panel.GBP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]
2020-08-27 Move "Production" folder
    [Weather-MM-Carrier-Panel.GBL, Weather-MM-Carrier-Panel.GBO, Weather-MM-Carrier-Panel.GBP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]
2020-09-10 Implemented SPI bus changes
    Re-panelized and new gerbers
    [Weather-MM-Carrier-Panel.brd, Weather-MM-Carrier.brd, Weather-MM-Carrier.sch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]
2020-12-03 Update names
    Updating Hardware board file names to match MicroMod naming conventions. Removing unneeded ZIP folder for Hardware files.
    [MicroMod_Weather_Carrier.brd, MicroMod_Weather_Carrier.sch]
2023-08-21 Update library and pins
    Update to use new Weather Meter Kit Arduino library
    Added pin declarations for other processor boards

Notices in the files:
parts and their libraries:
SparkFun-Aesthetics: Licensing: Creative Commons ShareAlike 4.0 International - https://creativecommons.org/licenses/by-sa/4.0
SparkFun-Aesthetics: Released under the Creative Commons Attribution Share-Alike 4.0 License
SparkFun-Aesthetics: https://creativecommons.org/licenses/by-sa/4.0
